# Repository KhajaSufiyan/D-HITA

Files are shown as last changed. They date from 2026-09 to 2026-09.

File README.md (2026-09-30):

# D-HITA — Dual-band Helmet-Integrated Tactical Antenna

**SIH26185 · Ministry of Home Affairs / National Security Guard (Police II Division) · Category: Hardware**  
**Team: Tech Elite-X (Team ID: 150092) · Theme: Robotics and Drones**

A lightweight, flexible, low-profile antenna that moves tactical-radio and body-worn-video antennas from the vest to the helmet, for NSG operators working in urban close-quarter-battle (CQB) environments. It is **passive** (no battery, MCU or switch), covers **UHF** (radio) and **L-band** (video) with two independent probe-fed microstrip patches on Kapton flex, and uses the underside ground plane as a head-isolation shield. Each band has its own U.FL output and 50 Ω coax pigtail.

## Status — read this first

| Stage | State |
|---|---|
| Problem analysis, requirements | Done (numeric targets partly `[TO BE CLARIFIED]`) |
| EM simulation (CST Studio Learning Edition) | **Done for flat board (v1); curved-on-helmet (v2) partly done** |
| Flex-PCB artwork / fabrication | **Not started** |
| VNA / radiation measurements | **None — everything below is simulated, not measured** |
| Helmet + head simulation | Helmet shell modelled in v2; head model not documented in this repo |

## Headline simulation results

Two design versions exist. They are **different antennas** — do not compare rows across versions without reading the notes.

| | v1 — flat combined board (R2, 2026-09-28) | v2 — curved separated boards on helmet (2026-09-29) |
|---|---|---|
| Layout | One 250 × 445 mm flex sheet carrying both patches | Two independent curved flex parts on a spherical helmet shell |
| UHF resonance | 460 MHz | 422 MHz (target 436) |
| UHF S11 | −9.6 dB | −7.6 dB |
| UHF radiation efficiency | 74 % (−1.319 dB) | −3.418 dB (~46 %) |
| UHF gain | 6.84 dBi | −0.96 dBi (IEEE) |
| UHF patch | 170.4 × 148.8 mm, probe-fed | 94 mm shorted quarter-wave patch |
| L-band resonance | 1364 MHz | ~1364 MHz (marker TBC) |
| L-band S11 | −10.15 dB | TBC |
| L-band radiation efficiency | 92 % (−0.35 dB) | −0.279 dB (~94 %) |
| L-band gain | 7.39 dBi | 6.36 dBi (IEEE) |
| L-band −10 dB bandwidth | ~35 MHz | not recorded |

Notes: v2 UHF gain is dominated by mismatch (monitor at 436 MHz, resonance at 422 MHz) and lossy aramid helmet material (assumed εr 3.8, tan δ 0.02, not vendor-confirmed). UHF −10 dB bandwidth has never been measured. Full detail: [`simulation/dhita_geometry_spec_v2.md`](simulation/dhita_geometry_spec_v2.md) and [`hardware/d-hita_rf_frontend_CONFIG.json`](hardware/d-hita_rf_frontend_CONFIG.json).

## Acceptance rule

Hit the target; if not, within a **30 % buffer** of target is accepted (e.g. S11 ≤ −7 dB against a −10 dB target).

## Repository map

| Folder | Contents |
|---|---|
| [`docs/`](docs/) | Project summary PDF, decision log, open items, requirement traceability |
| [`requirements/`](requirements/) | SIH26185 requirements, working numeric targets, and a source register (UHF band, NSG tenders) |
| [`research/`](research/) | Reference list (five papers) — comparison matrix not yet built |
| [`simulation/`](simulation/) | CST settings, materials, lessons learned, geometry spec v2, helmet model, results |
| [`hardware/`](hardware/) | Build guide, parts list (CSV), config + connection JSON, archived rejected design |
| [`measurement/`](measurement/) | VNA procedure pointer and log templates (no data yet) |
| [`analysis/`](analysis/) | Python tools: S11 report, sim-vs-measurement comparison, flat-artwork converter, helmet STL generator (self-tested) |
| [`presentation/`](presentation/) | Official SIH 2026 slide deck (PPTX, PDF, and slide previews) |
| [`images/`](images/) | Screenshots and renders (to be added) |

## Known inconsistencies (being resolved)

- The build guide, parts CSV and config/connection JSON describe **v1** (single flat 250 × 445 mm sheet). v2 requires **two separate flex parts**. These files have not yet been updated to v2 — see [`hardware/README.md`](hardware/README.md).
- `docs/SIH26185_Project_Summary_DHITA.pdf` is dated 10 Sep 2026 and states that no simulation results exist; that is no longer true.
- The UHF 403–470 MHz band now has a primary source (MHA/CRPF QRs, June 2025, NSG co-signed) — see [`requirements/sources.md`](requirements/sources.md).
- **The L-band video-link frequency is unsourced.** The NSG body-worn-video tender describes relay over a cellular network and the internet, with no RF band or L-band requirement; the earlier MHA camera QRs list 4G/3G + Wi-Fi. The PS still asks for L-band, but the 1350–1450 MHz figure has no source. Details and next step in [`requirements/sources.md`](requirements/sources.md) §3.

## Open items

See [`docs/OPEN_ITEMS.md`](docs/OPEN_ITEMS.md). Highlights: exact NSG L-band video frequency, bulkhead connector (SMA vs TNC), RF shield material, helmet model and mounting method, 3.5 mm flexible substrate realisation (Kapton over foam/silicone), UHF bandwidth and match on the curved board.

## Team

Roster `[TO BE CLARIFIED]` — see [`TEAM.md`](TEAM.md) (template, to be filled in).

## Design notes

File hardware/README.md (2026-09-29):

# Hardware

| File | What it is |
|---|---|
| `d-hita_rf_frontend_GUIDE.md` | Step-by-step build guide, revision R2 (fabrication, assembly, VNA bring-up, helmet validation) |
| `d-hita_rf_frontend_PARTS.csv` | Bill of materials (16 line items; estimated costs as recorded, currency not stated) |
| `d-hita_rf_frontend_CONFIG.json` | Full project config: substrate, board geometry, per-band results, parts, connections, removed parts, open items |
| `d-hita_rf_frontend_ELECTRICAL_CONNECTIONS.json` | Signal and ground connections |
| `d-hita_rf_frontend_MECHANICAL_CONNECTIONS.json` | Physical placement and offsets |
| `archive/` | Rejected designs, kept for the record — **do not build** |

## ⚠ These files describe v1 (single flat board), not v2

The guide, BOM and JSON files specify **one** 250 × 445 mm Kapton sheet carrying both patches (UHF 170.4 × 148.8 mm, L-band 55.1 × 74 mm). The v2 design (`../simulation/dhita_geometry_spec_v2.md`) uses **two separate curved flex parts** with a 94 mm shorted UHF patch and no shared ground. Until the hardware files are regenerated for v2, do not send the guide's §1.1 artwork spec to a fab house. Developed (flat) dimensions for the v2 UHF part are in the geometry spec; L-band substrate and ground sizes are still TBC there.

## Fabrication caveat

Solid 3.5 mm Kapton laminate is not a stock product. The plan is a thin Kapton patch/feed layer over a flexible foam or silicone spacer, to be confirmed with the flex fab house. Kapton-over-foam properties will differ from the simulated solid εr 3.5 stack.

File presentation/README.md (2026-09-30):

# D-HITA Presentation — Smart India Hackathon 2026

Official idea presentation deck for **SIH 2026** (Problem Statement ID: **SIH26185**).

- **Team Name:** Tech Elite-X
- **Team ID:** 150092
- **Theme:** Robotics and Drones
- **Category:** Hardware
- **Problem Statement Title:** Helmet Mounted Conformal Antenna For Tactical Communication In Urban CQB Environments
- **Video Demonstration:** [YouTube Video Link](https://youtu.be/ssRnNJ8aVqI)
- **Repository:** [GitHub Link](https://github.com/KhajaSufiyan/D-HITA)

---

## Deck Files

| Format | File Path | Description |
|---|---|---|
| **PowerPoint (.pptx)** | [`SIH2026-IDEA-Presentation-Format.pptx`](SIH2026-IDEA-Presentation-Format.pptx) | Widescreen 16:9 presentation deck with embedded links |
| **PDF (.pdf)** | [`SIH2026-IDEA-Presentation-Format.pdf`](SIH2026-IDEA-Presentation-Format.pdf) | High-resolution PDF export |
| **Slide Images** | [`slides/`](slides/) | High-resolution PNG renders for each slide (4320 × 2430) |
| **Layout Reference** | [`sih_deck_structure_reference.md`](sih_deck_structure_reference.md) | SIH presentation deck structural layout guideline |

---

## Slide Previews & Breakdown

### Slide 1: Title & Team Details
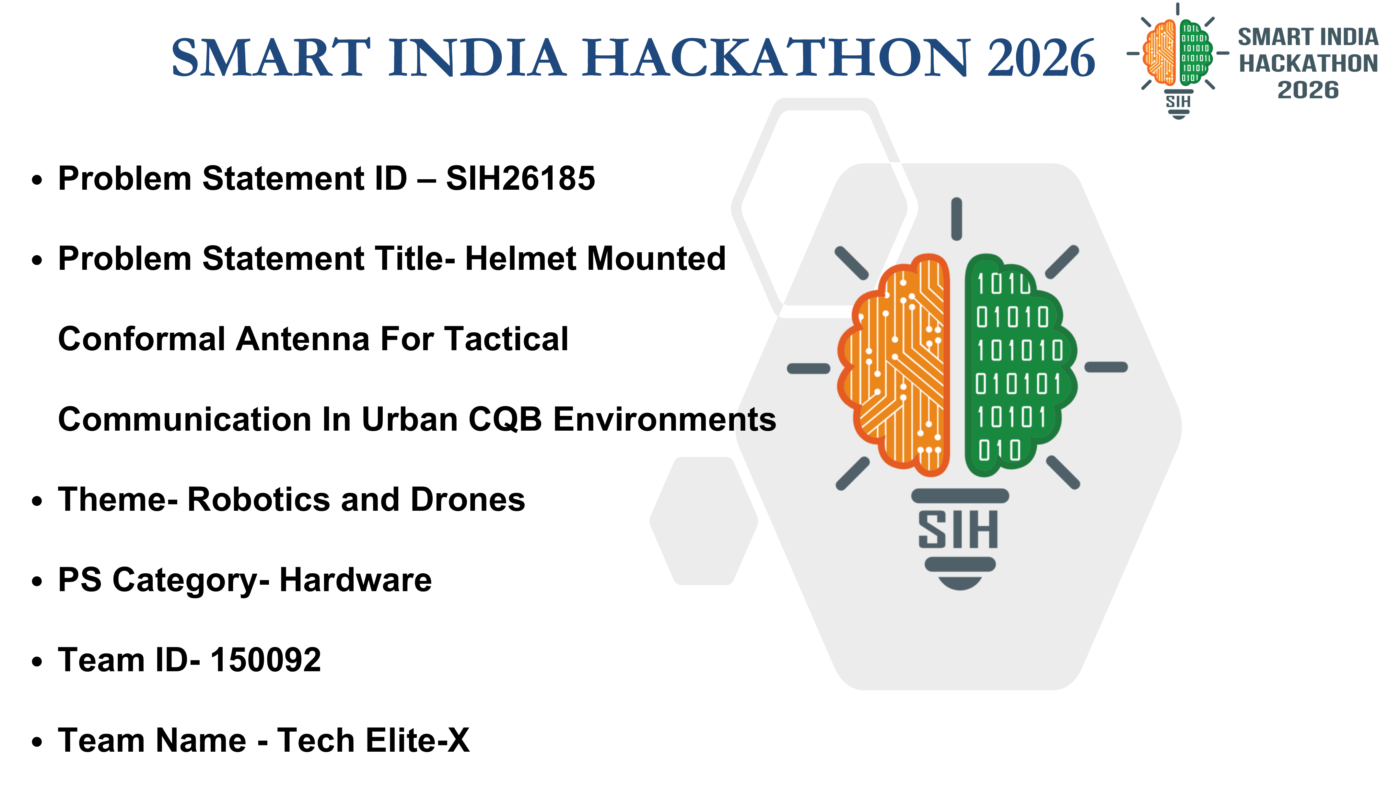
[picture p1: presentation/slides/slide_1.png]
Slide 1


- **Event:** Smart India Hackathon 2026
- **Problem Statement ID:** SIH26185
- **Problem Statement Title:** Helmet Mounted Conformal Antenna For Tactical Communication In Urban CQB Environments
- **Theme:** Robotics and Drones
- **Category:** Hardware
- **Team ID:** 150092
- **Team Name:** Tech Elite-X

---

### Slide 2: Problem, Solution & Uniqueness
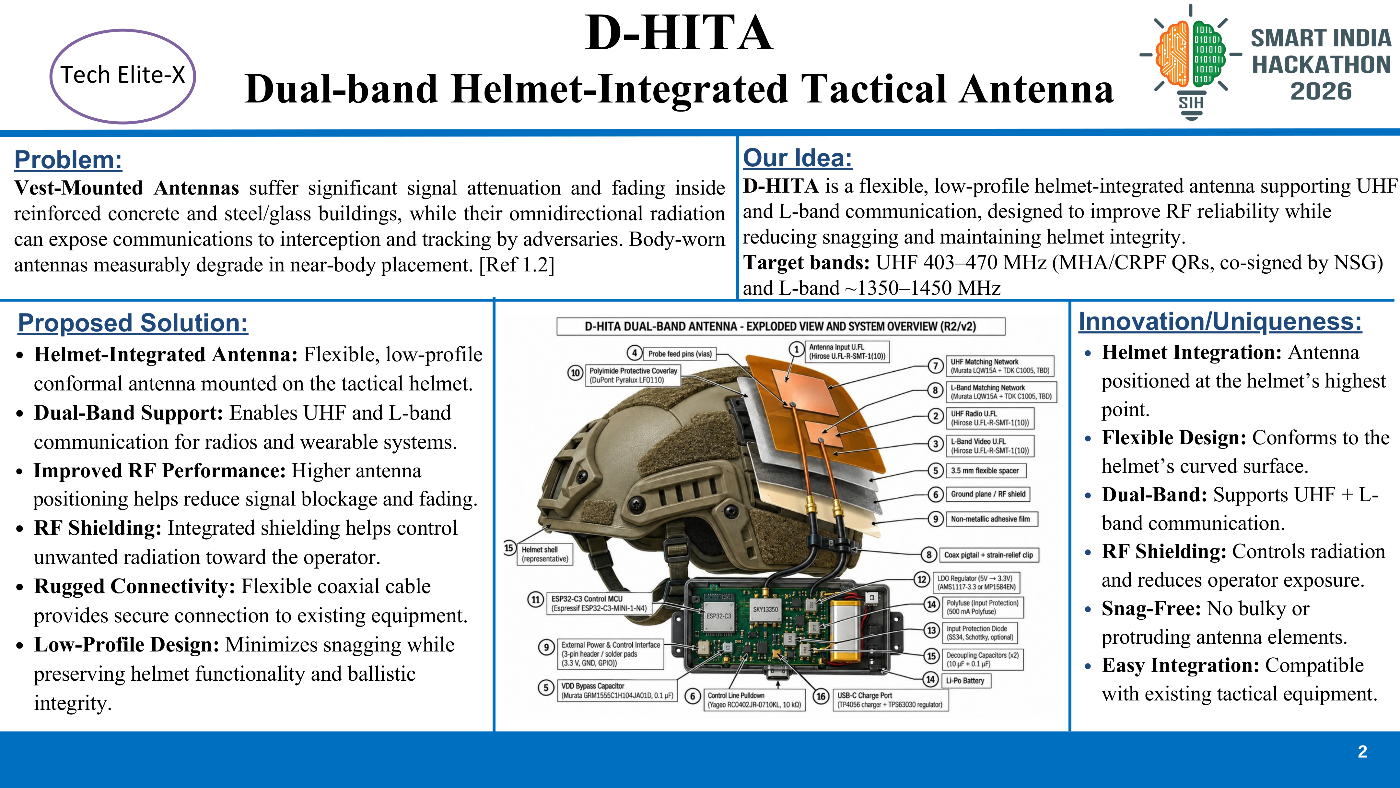
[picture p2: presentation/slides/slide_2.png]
Slide 2


- **Problem:** Vest-mounted antennas suffer severe attenuation and fading inside reinforced concrete / steel buildings; body shadowing degrades radiation performance measurably.
- **Our Idea:** Flexible, low-profile helmet-integrated dual-band antenna supporting UHF (403–470 MHz) and L-band (~1350–1450 MHz) to maximize RF line-of-sight while eliminating snagging.
- **Proposed Solution:** Conformal mount on ballistic helmet, dual-band coverage, integrated RF shielding layer to protect the operator, rugged coaxial interconnects.
- **Innovation / Uniqueness:** Helmet apex placement, flexible curved substrate, zero snagging, no cutting of helmet shell (ballistic integrity preserved).

---

### Slide 3: Technical Approach
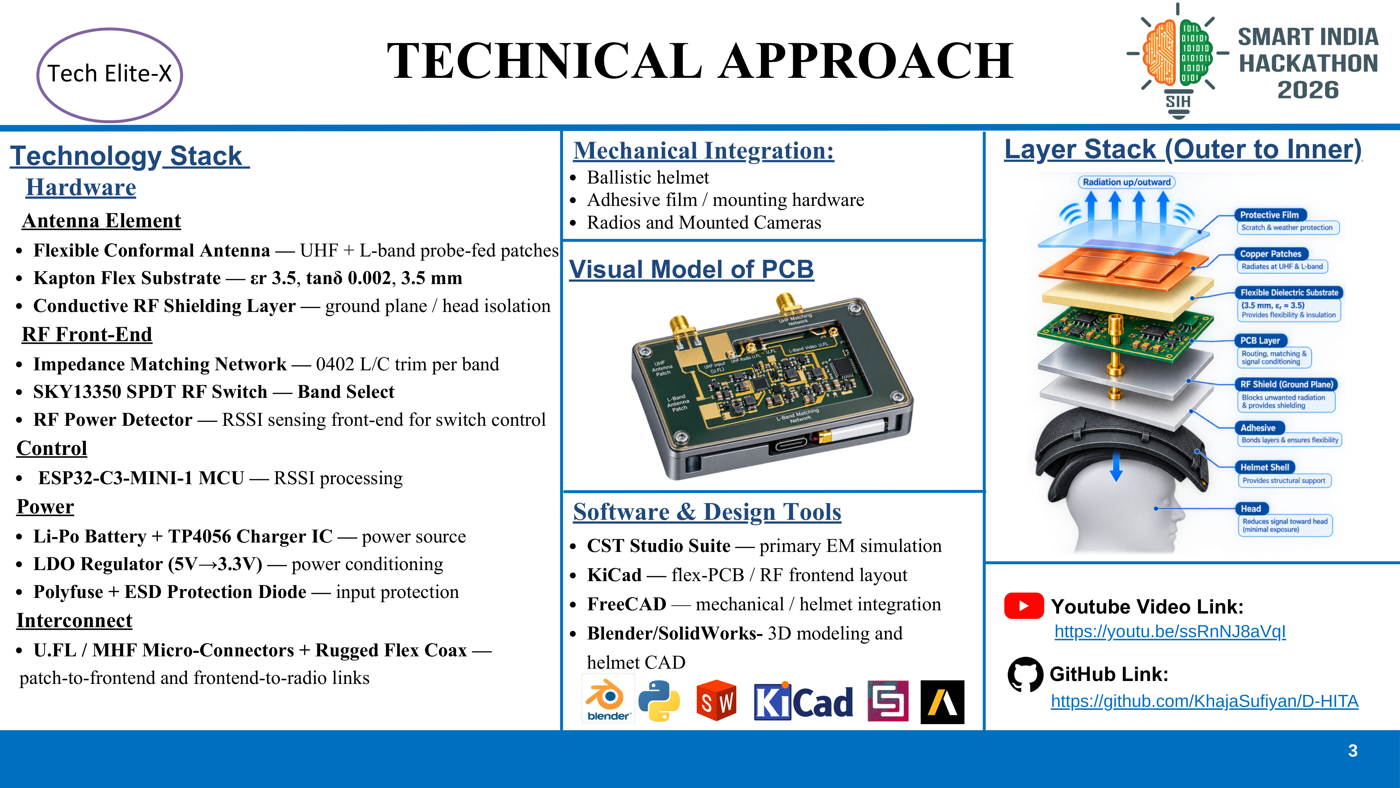
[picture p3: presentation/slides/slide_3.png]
Slide 3


- **Antenna Element:** Flexible conformal patch (Kapton flex substrate $\varepsilon_r=3.5, \tan\delta=0.002, 3.5\text{ mm}$), conductive RF shielding ground plane.
- **RF Front-End:** Impedance matching network (0402 L/C trim), SKY13350 SPDT RF switch, RF power detector.
- **Control & Power:** ESP32-C3-MINI-1 MCU, Li-Po battery + TP4056 charger, 3.3V LDO regulator, ESD diode and Polyfuse protection.
- **Mechanical & Software:** CST Studio Suite (EM simulation), KiCad (RF flex layout), FreeCAD / Blender / SolidWorks (helmet 3D CAD).
- **Direct Links:**
  - YouTube: [https://youtu.be/ssRnNJ8aVqI](https://youtu.be/ssRnNJ8aVqI)
  - GitHub: [https://github.com/KhajaSufiyan/D-HITA](https://github.com/KhajaSufiyan/D-HITA)

---

### Slide 4: Feasibility and Viability
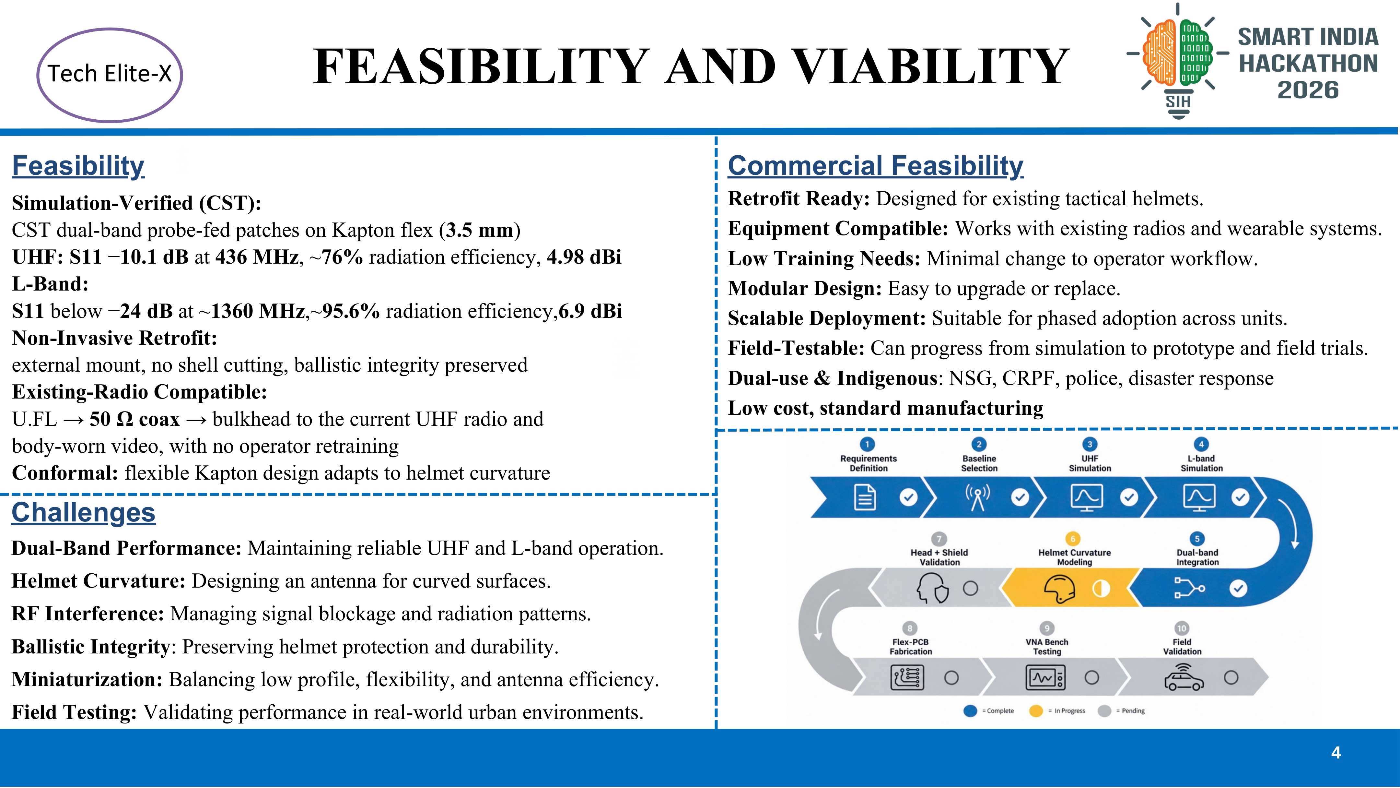
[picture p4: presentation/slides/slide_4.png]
Slide 4


- **Simulation-Verified (CST):**
  - **UHF:** $S_{11} = -10.1\text{ dB}$ at $436\text{ MHz}$, $\sim 76\%$ radiation efficiency, $4.98\text{ dBi}$ gain.
  - **L-Band:** $S_{11} < -24\text{ dB}$ at $\sim 1360\text{ MHz}$, $\sim 95.6\%$ radiation efficiency, $6.9\text{ dBi}$ gain.
- **Commercial Feasibility:** Non-invasive retrofit for standard ballistic helmets (ACH/MICH), existing radio compatible via 50 $\Omega$ coax, zero operator retraining needed.
- **Development Roadmap:** Requirements Definition $\to$ Baseline Selection $\to$ UHF Simulation $\to$ L-band Simulation $\to$ Dual-band Integration $\to$ Helmet Curvature Modeling $\to$ Head + Shield Validation $\to$ Flex-PCB Fabrication $\to$ VNA Bench Testing $\to$ Field Validation.

---

### Slide 5: Impact and Benefits
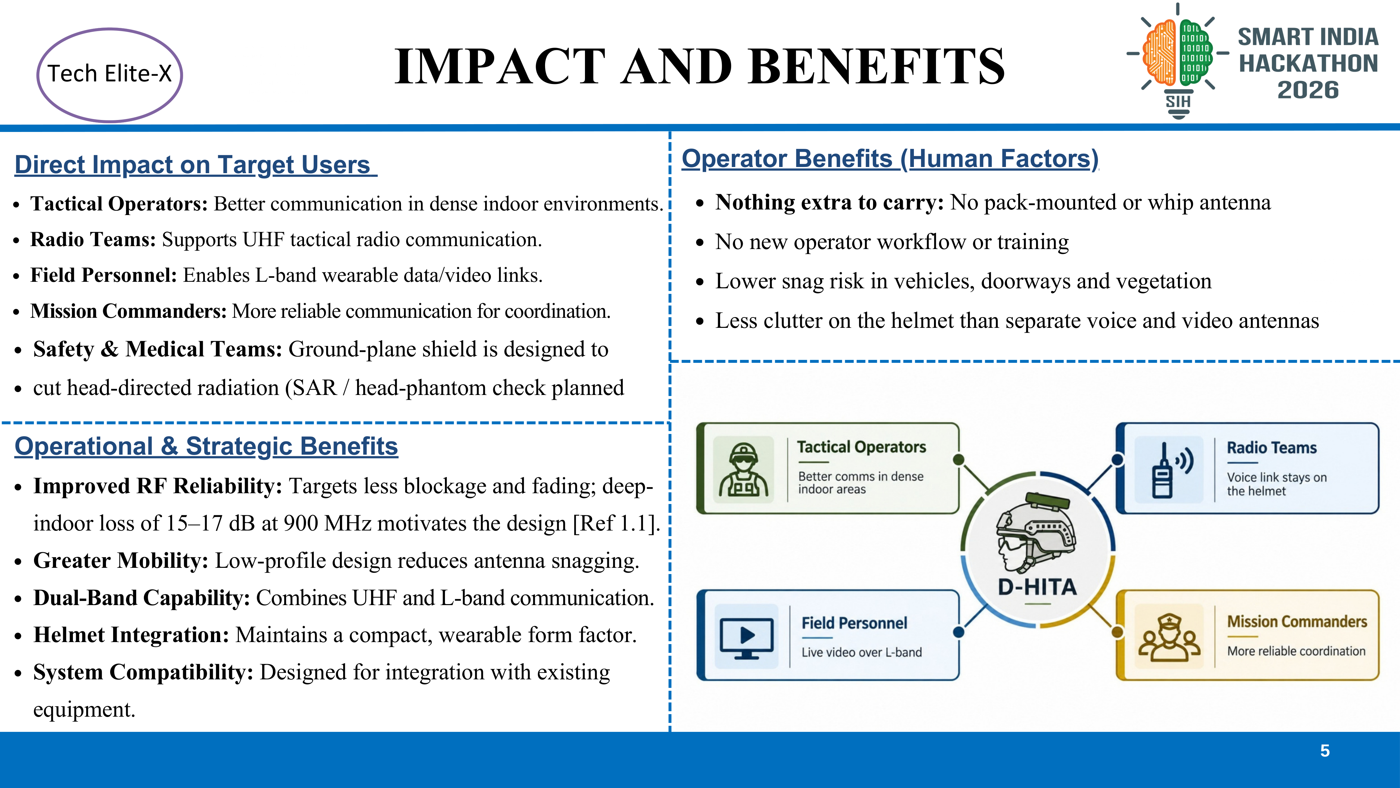
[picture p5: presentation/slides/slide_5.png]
Slide 5


- **Direct Impact on Target Users:** Tactical operators, radio teams, field personnel (live video over L-band), mission commanders, safety & medical teams (radiation shielded).
- **Operational & Strategic Benefits:** 15–17 dB deep-indoor loss mitigation, snag-free movement in doorways/vehicles, dual-band voice + video convergence in one wearable form factor.
- **Human Factors:** Nothing extra to carry, no pack-mounted whip antennas, less helmet clutter.

---

### Slide 6: Research and References
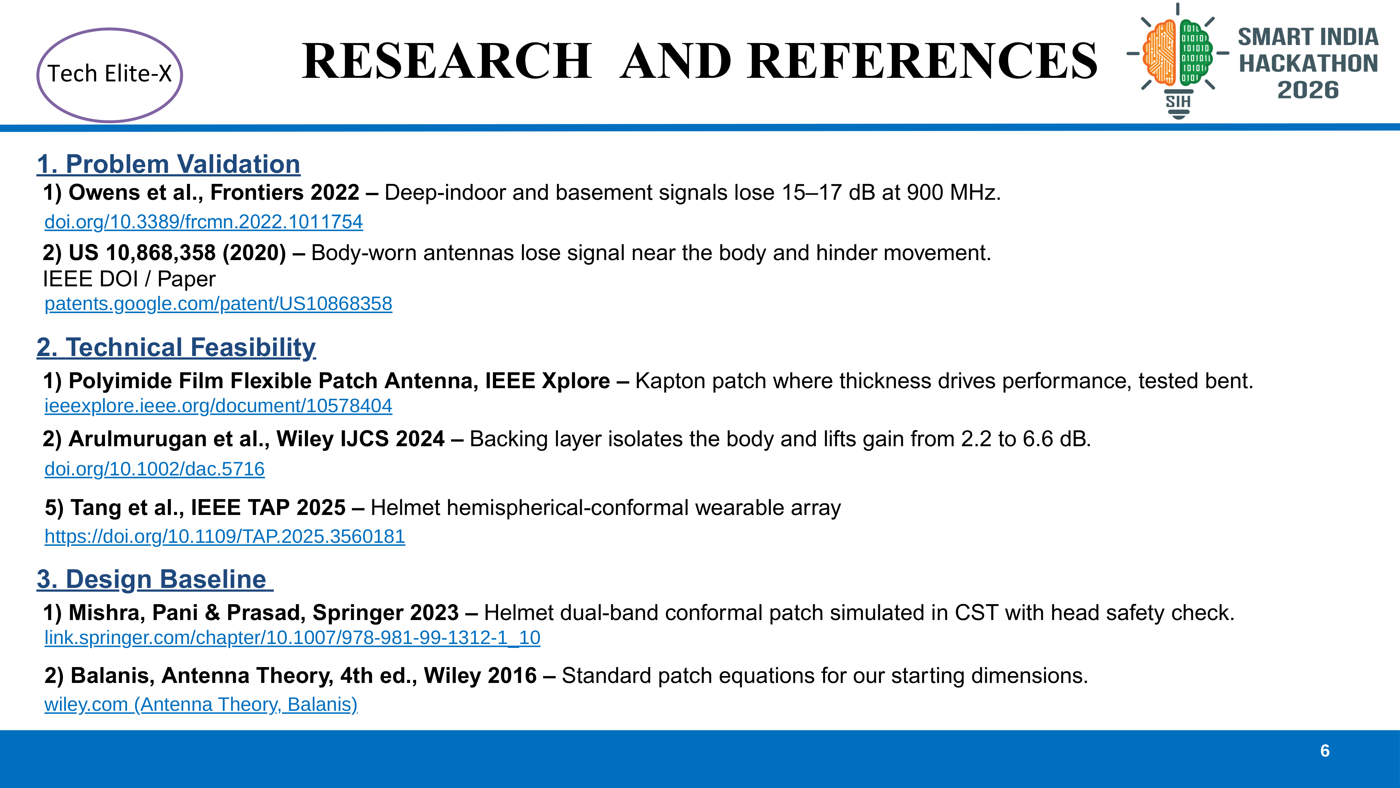
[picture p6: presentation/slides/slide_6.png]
Slide 6


1. **Problem Validation:**
   - Owens et al., *Frontiers 2022* — Deep-indoor and basement signals lose 15–17 dB at 900 MHz. [doi:10.3389/frcmn.2022.1011754](https://doi.org/10.3389/frcmn.2022.1011754)
   - US Patent 10,868,358 (2020) — Body-worn antennas lose signal near the body and hinder movement. [Google Patents](https://patents.google.com/patent/US10868358) / [IEEE](https://ieeexplore.ieee.org/document/10969548)
2. **Technical Feasibility:**
   - Polyimide Film Flexible Patch Antenna, *IEEE Xplore* — Kapton patch where thickness drives performance, tested bent. [IEEE Document 10578404](https://ieeexplore.ieee.org/document/10578404)
   - Arulmurugan et al., *Wiley IJCS 2024* — Backing layer isolates the body and lifts gain from 2.2 to 6.6 dB. [doi:10.1002/dac.5716](https://doi.org/10.1002/dac.5716)
   - Tang et al., *IEEE TAP 2025* — Helmet hemispherical-conformal wearable array. [doi:10.1109/TAP.2025.3560181](https://doi.org/10.1109/TAP.2025.3560181)
3. **Design Baseline:**
   - Mishra, Pani & Prasad, *Springer 2023* — Helmet dual-band conformal patch simulated in CST with head safety check. [Springer Chapter](https://link.springer.com/chapter/10.1007/978-981-99-1312-1_10)
   - Balanis, *Antenna Theory*, 4th ed., Wiley 2016 — Standard patch equations for design dimensions.

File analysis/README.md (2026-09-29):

# Analysis

## `flatten_dimensions.py`

Converts the chord (CAD) dimensions of the curved v2 shells to developed arc lengths for flex-PCB artwork, using `s = r·asin(x/r)` at the substrate mid-radius r = 127.75 mm (formula from `simulation/dhita_geometry_spec_v2.md`).

```
python3 analysis/flatten_dimensions.py
```

Check against the spec: the UHF substrate, ground and patch reproduce the spec's developed sizes exactly (126.1 × 94.1, 123.8 × 92.0, 96.3 × 60.6 mm). The **L-band patch does not quite match**: the script gives 55.5 × 75.1 mm, the spec lists 55.4 × 74.8 mm (0.1 / 0.3 mm apart). Both are within the few-percent distortion the spec already warns about for flattening a sphere, but one of the two calculations used a different radius or method — settle which before sending artwork to a fab house.

## `sparams.py`, `s11_report.py`, `compare_sim_meas.py`, `selftest.py`

Tools for when CST exports and VNA data exist (none in the repo yet). No dependencies beyond numpy and matplotlib.

| Script | Does |
|---|---|
| `sparams.py` | Loads Touchstone (`.s1p` / `.s2p`, RI/MA/DB, any unit) and text/CSV exports (dB, magnitude, Re/Im, mag/phase) |
| `s11_report.py` | Resonance, S11 minimum, −10 dB and −7 dB bandwidth, checked against the acceptance rule (S11 ≤ −10 dB pass, ≤ −7 dB accepted; L-band BW ≥ 40 MHz pass, ≥ 28 MHz accepted; UHF resonance inside 403–470 MHz), plus a PNG plot |
| `compare_sim_meas.py` | Resonance shift, match-depth change and bandwidth ratio between a simulated and a measured trace, plus an overlay plot |
| `selftest.py` | 20 checks against a synthetic resonator with a known analytic answer (resonance, S11 minimum and both bandwidths agree exactly; file formats round-trip; port ordering; plots are written) |

```
python3 analysis/selftest.py
python3 analysis/s11_report.py results/v2_uhf.s1p --band uhf --target 436 --plot uhf.png
python3 analysis/s11_report.py export.txt --band lband --funit GHz --fmt db      # CST 1D text export
python3 analysis/compare_sim_meas.py sim.s1p vna.s1p --plot compare.png
```

Limits: the CST text-export layout hasn't been checked against a real export from your version of CST, so if a file fails to load, send me a sample. The self-test uses synthetic data only. Nothing here reads gain or efficiency; S11 only.

## `make_helmet_shell.py`

Generates the idealised v2 helmet shell as an STL (`simulation/helmet/helmet_shell_R125_t5.6.stl`) from the CST spec, and self-checks that the mesh is watertight and its volume matches the analytic value. See `simulation/helmet/README.md`.

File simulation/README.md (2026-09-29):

# Simulation (CST Studio Suite, Learning Edition)

| File | Purpose |
|---|---|
| `cst_software_settings.md` | Project units and the `FR4_substrate` material dialog dump. **Note:** this is FR4 with ε = 1 and no loss — it does not describe the `Kapton_flex` or aramid materials the designs actually use (see `materials.md`). |
| `materials.md` | `Kapton_flex`, `Aramid` and PEC definitions **reconstructed from the spec values** (not exported from CST — verify against your project) |
| `helmet/` | Helmet shell STL generated from the v2 spec, and the (still undefined) head-model plan |
| `cst_lessons_and_lband_plan.md` | Ten lessons from the UHF runs and the L-band build plan (2026-09-27) |
| `dhita_geometry_spec_v2.md` | v2 curved, separated boards: construction method, parameters, tables, developed dimensions, results, open issues (2026-09-29) |
| `results/` | Exported S-parameters, patterns and screenshots (none added yet — see its README) |

## Design versions

- **v1 — flat combined board** (R2, 2026-09-28): single Kapton flex sheet, 250 × 445 mm, h = 3.5 mm. Parameters are in `hardware/d-hita_rf_frontend_CONFIG.json`.
- **v2 — curved separated boards on helmet** (2026-09-29): parameters and tables in `dhita_geometry_spec_v2.md`.

Suggested git tags once the CST files are committed: `v1-flat`, `v2-curved`.

## Solver notes

Learning Edition cap: 20,000 tetrahedra (the lessons file also mentions 100k — confirm). v2 settings: cells per max model box edge = 7, adaptive mesh passes min = max = 2. Check the mesh cell count before clicking Start; update farfield and power-loss monitors to the actual resonance after every run.

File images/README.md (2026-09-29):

# Images

To be added:

- CST screenshots: flat v1 model, curved v2 model (UHF and L-band boards on the helmet shell)
- S11 plots for each band and version
- Farfield / 3D pattern plots
- Helmet model render

Do not add the R1 render of the rejected active-switch design here; it lives in `../hardware/archive/`.

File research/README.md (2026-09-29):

# Research

Five papers have been identified and read. Links are by DOI only; PDFs are deliberately not stored here (copyright).

| Reference | Role |
|---|---|
| Herold, Griffiths, Fung et al., IEEE MILCOM 2007, "Lightweight, High-Bandwidth Conformal Antenna System for Ballistic Helmets." DOI 10.1109/MILCOM.2007.4455055 | Direct ballistic-helmet conformal antenna prior art |
| Lebaric & Tan, IEEE MILCOM 2000, "Ultra-wideband RF helmet antenna." DOI 10.1109/MILCOM.2000.905081 | Early helmet antenna prior art |
| Li et al., 2023, "Research Progress on Helmet Antenna in Individual Soldier Communication System." DOI 10.11999/JEIT220613 | Helmet antenna review / background |
| Nepa & Rogier, IEEE Antennas & Propagation Magazine, 2015. DOI 10.1109/MAP.2015.2472374 | Wearable / conformal antenna background |
| Tang et al., IEEE TAP 2025, "A Helmet-Based Hemispherical-Conformal Wearable Array Antenna …" DOI 10.1109/TAP.2025.3560181 | Recent helmet conformal-array prior art (full title to re-verify) |

## Not yet done

- Comparison matrix (frequency, topology, dimensions, substrate, thickness, gain, bandwidth, efficiency, conformality, helmet integration, shielding, testing, limitations)
- Gap analysis (3–5 defensible gaps)
- Search for missing evidence only: UHF helmet antennas, dual-band UHF/L-band designs, shielding/head loading, patents

## Operational sources

- SIH26185 problem statement (MHA / NSG)
- MHA/CRPF QRs for digital UHF radio sets (June 2025) and the NSG 2026 tender listings (radio sets, repeater, body-worn video) — URLs and findings in [`../requirements/sources.md`](../requirements/sources.md)

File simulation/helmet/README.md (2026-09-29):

# Helmet and head models

## Helmet shell — `helmet_shell_R125_t5.6.stl`

The idealised helmet used in the v2 CST model, as a mesh you can open in FreeCAD, SolidWorks, Blender or any STL viewer (units mm).

| Parameter | Value | From |
|---|---|---|
| Outer radius `hR` | 125 | `../dhita_geometry_spec_v2.md` |
| Thickness `ht` | 5.6 (inner radius 119.4) | same |
| Centre | (0, 0, −126); crown apex at Z = −1 | same |
| Extent | Hemisphere, Z ≥ −126 | same |
| Material in CST | Aramid, εr 3.8, tan δ 0.02 (assumed) | see `../materials.md` |

Regenerate or change parameters: `python3 analysis/make_helmet_shell.py --help` (run from the repo root). The script self-checks that the mesh is watertight and that its volume matches the analytic shell volume (within 1 %).

What it is **not**: a real ballistic-helmet shape, and it does not include the antenna boards. The real helmet model and shell material are still `[TO BE CLARIFIED]`.

## Head model — not yet defined

No head model is documented anywhere in the project files, so none is provided. The head + helmet simulation is still open. Decisions needed before building it:

| Item | Status |
|---|---|
| Head geometry (sphere, ellipsoid, or CST/voxel head) | TBD |
| Head size and air/liner gap to the helmet inner surface (radius 119.4 mm) | TBD |
| Tissue properties at 403–470 MHz and at the L-band frequency | TBD — take from a published tissue database (for example the IT'IS Foundation database) or CST's built-in tissue library, and cite it |
| Homogeneous vs layered (skin / bone / brain) | TBD |
| What to report | Change in resonance, S11 and efficiency versus helmet-only; head-directed radiation; SAR if feasible |

Things to keep in mind:
- The v2 helmet inner radius (119.4 mm, so a hemisphere about 239 mm across) is considerably larger than a typical adult head. Either place a smaller head inside it deliberately, with the gap defined, or revisit the helmet radius.
- A lossy head volume adds a lot of mesh. The v2 model was already tuned to stay under the Learning Edition tetrahedron cap (cells per box edge = 7, adaptive passes = 2), so expect to hit the cap. Check the mesh count before starting, and consider HFSS Student or a reduced model if needed.
- Transmit power (see `../../requirements/sources.md` §4) determines whether SAR is a real concern.

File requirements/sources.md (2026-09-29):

# Source Register

Primary sources for the frequency and equipment requirements. Read on 2026-09-30 through automated page retrieval, which summarises rather than transcribes: open each PDF and note the section/page numbers before citing in the deck or report.

## 1. UHF band — 403–470 MHz (now sourced)

**Document:** QRs/TDs of Digital Hand-Held UHF Transceiver Set, Digital UHF Base/Mobile Transceivers Set and Digital UHF Repeater Set — Ministry of Home Affairs / CRPF Communication & IT Directorate, June 2025.
**URL:** https://www.mha.gov.in/sites/default/files/2025-06/AppQRsTDsDigiUHF_06062025.pdf

What it says:
- 403–470 MHz ("full band") for all three radio types
- Power classes: 1.4 W hand-held, 20 W mobile/base, 40 W or more repeater
- Approval pages include an NSG signatory alongside CRPF, CISF, ITBP, BSF, SSB, Assam Rifles and DCPW representatives

This replaces the "source not in repo" caveat on the UHF band.

## 2. NSG 2026 procurement (archive listing)

Archive index: https://nsg.gov.in/archive-tender/current-tenders

| Item | Bid ref | Date on archive | Document |
|---|---|---|---|
| Wireless Body Worn Video System | GEM/2026/B/7517372 | 03-06-2026 | https://nsg.gov.in/resources/uploads/TenderManagement/178048996348.pdf |
| Digital UHF Hand Held Radio Sets — 4 W | GEM/2026/B/7540163 | 23-06-2026 | https://nsg.gov.in/resources/uploads/TenderManagement/178220161366.pdf |
| Digital UHF Hand Held Radio Sets — 20 W | GEM/2026/B/7540671 | 23-06-2026 | https://nsg.gov.in/resources/uploads/TenderManagement/178220186760.pdf |
| Digital UHF Repeater Set — 40 W | GEM/2026/B/7540825 | 23-06-2026 | https://nsg.gov.in/resources/uploads/TenderManagement/178220202420.pdf |
| Digital UHF Hand Held Radio Sets — 4 W (re-listed) | GEM/2026/B/7816513 | 10-08-2026 | https://nsg.gov.in/resources/uploads/TenderManagement/178659795126.pdf |
| Digital UHF Hand Held Radio Sets — 20 W (re-listed) | GEM/2026/B/7817167 | 10-08-2026 | https://nsg.gov.in/resources/uploads/TenderManagement/178659814948.pdf |
| Digital UHF Repeater Set — 40 W (re-listed) | GEM/2026/B/7818796 | 10-08-2026 | https://nsg.gov.in/resources/uploads/TenderManagement/178659832414.pdf |

Dates and references are as listed on the archive page; two of the PDFs (video, 20 W) were opened and matched their listings (video: 148 pieces, "as per MHA QRs (V3)"; 20 W: 188 units, "as per MHA QR (V2)"). The other five PDFs were not opened.

## 3. Finding: the video link is not shown to be L-band

- The NSG body-worn-video tender says the camera must relay feeds in real time in online mode and, when there is no **cellular network**, record and store them and relay later or by physical connection to a computer. The accompanying software must feed a central server or incident command post **over the internet**. The document gives no RF band, antenna or L-band requirement, and points to the MHA QRs (V3) for the rest.
- The earlier MHA/CRPF body-worn-camera QRs (for RAF, 6 Jun 2021, https://www.mha.gov.in/sites/default/files/QRs_BodyWornCameraSystems_25062021.PDF) specify "4G/3G + Wi-Fi", IP streaming and a cloud platform, and no L-band or other RF frequency.
- The V3 QRs themselves were not found or read.

**What this means.** The SIH26185 problem statement still asks for L-band, so the requirement stands. But the 1350–1450 MHz "video link" figure now has no source, and the only NSG camera evidence points at cellular/Wi-Fi. Resolve this before spending more simulation time on L-band tuning: ask the SIH mentors / NSG nodal contact which L-band frequency they mean, and look for the MHA BWC QRs (V3).

## 4. Also worth checking

The NSG radio tenders are for 4 W, 20 W and 40 W sets (the QR lists 1.4 W for the hand-held class). A helmet-mounted antenna sits close to the head, so transmit power matters for head exposure and for the "SAR if feasible" item in the project plan. Confirm which power class would actually feed the helmet antenna.

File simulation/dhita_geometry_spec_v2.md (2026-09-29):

# D-HITA Geometry Spec v2 — separated curved boards (CST, uL = 94)

Status: UHF stack complete and solving. L-band ground/substrate footprint TBC.
Date: 2026-09-29. Supersedes the earlier flat combined-board spec.

## Construction method (sphere-shell, replaces the failed Bend tool)

Every antenna layer is a spherical shell segment built the same way:

1. Sphere, centre (0, 0, hZ), outer radius = R_outer
2. Sphere `t`, centre (0, 0, hZ), radius = R_inner -> Boolean **Subtract**
3. Brick `c`, X/Y range as tabled, Z from hZ to 20, Vacuum -> Boolean **Intersect**
4. Transform -> Rotate about global X, pivot (0, 0, hZ), "Shape center" UNCHECKED, OK once

Choose **None** on every Shape Intersection pop-up. `c` must show a solid-cube icon
before the Intersect; a sheet icon means a zero-thickness brick, which silently turns
the shell into a 2D sheet and breaks the mesher with "self-intersections".

## Parameters

| Name | Value | Meaning |
|---|---|---|
| hR | 125 | helmet outer radius (mm) |
| hZ | -126 | helmet centre Z; crown apex at Z = -1 |
| ht | 5.6 | helmet shell thickness |
| h | 3.5 | substrate thickness |
| tc | 1 | conductor thickness |
| uL | 94 | UHF patch length |
| uFx | 12 | UHF feed distance from the short |
| band2L | 55.1 | L-band patch X length |
| band2W | 74 | L-band patch Y width |
| band2Px | 16 | L-band probe offset from patch centre |

## Helmet

Sphere centre (0, 0, -126), outer radius 125, inner radius 119.4 (= hR - ht),
cut to a hemisphere keeping Z >= -126. Material Aramid, er 3.8, tan d 0.02 (assumed,
not vendor-confirmed).

## Board topology — TWO SEPARATE PIECES

The UHF and L-band boards are independent. `gU/sU/pU` and `gL/sL/pL` are separate
shells with vacuum between them: no shared substrate, no shared ground, nothing
bridging the gap. Their centres are 49 deg apart on the helmet (-24 deg and +25 deg).

They must be fabricated as two separate flex parts. A single sheet spanning 49 deg
plus both board widths would be a dome section ~190 mm across, and flattening that
much double curvature requires gores. It is also not what is simulated.

The two ground planes are electrically isolated. The only common point in a real
build is the radio chassis, where both coax shields land. Bridging them on the
helmet changes both bands.

Keep-out gap, measured from the crown at the ground radius 125.5 mm:
- UHF ground near edge: 2.98 deg from the crown = 6.5 mm of arc
- L-band ground near edge: TBC
- Total gap approx **13 mm**, assuming gL runs to +/-47 mm in Y. Consistent with the
  ~12.7 mm figure recorded earlier. Confirm from the gL brick.

## UHF board — shorted quarter-wave patch, rotate X = -24 deg (lands on +Y side)

| Shape | Material | R inner | R outer | X range | Y range |
|---|---|---|---|---|---|
| gU ground | PEC | 125 | 126 | -57 .. +62 | -45 .. +45 |
| sU substrate | Kapton | 126 | 129.5 | -58 .. +63 | -46 .. +46 |
| pU patch | PEC | 129.5 | 130.5 | -47 .. +47 | -30 .. +30 |
| wU short wall | PEC | 125 | 130.5 | -47 .. -45 | -30 .. +30 |

X max of gU = `-47+uL+15`; X max of sU = `-46+uL+15`; X max of pU = `-47+uL`.

The wall deliberately reaches down to R 125, overlapping gU, so the two bond in the
mesh. A wall that only touches gU at R 126 does NOT connect: the resonance stays at
the unshorted value (~955 MHz) and CST reports self-intersections. Build order after
rotating wU: `sU` Boolean **Insert** wU, then `pU` Boolean **Add** wU.

Port 1: discrete edge, 50 ohm, radius 0, global coordinates (not WCS), defined after
rotation: (-35, 49.02, -15.9) -> (-35, 50.92, -11.62).
Lower end sits at r = 125.5 (inside gU), upper end at r = 130.0 (inside pU).

## L-band board — half-wave patch, rotate X = +25 deg (lands on -Y side)

| Shape | Material | R inner | R outer | X range | Y range |
|---|---|---|---|---|---|
| gL ground | PEC | 125 | 126 | TBC | TBC |
| sL substrate | Kapton | 126 | 129.5 | TBC | TBC |
| pL patch | PEC | 129.5 | 130.5 | -27.55 .. +27.55 | -37 .. +37 |

Port 2: discrete edge, 50 ohm, (16, -52.61, -13.19) -> (16, -54.52, -9.08).
Same radii as port 1. This port has worked reliably from the start.

To fill the TBC rows: History List -> the "define brick: component1:c" rows
immediately before `boolean intersect shapes: component1:gL, component1:c` and the
same for `sL` -> select the row and click Edit.

## Developed (flattened) dimensions — for flex-PCB artwork

Arc length s = r * asin(x / r), taken at the substrate mid-radius r = 127.75 mm.
Form both parts to a 127.75 mm spherical radius. The chord values in the tables
above are for CAD only; do not use them for artwork.

### UHF part

| Feature | Developed size |
|---|---|
| Substrate sU | 126.1 x 94.1 mm |
| Ground gU | 123.8 x 92.0 mm |
| Patch pU | 96.3 x 60.6 mm |
| Shorting wall | 2.2 mm wide, full 60.6 mm patch edge |
| Feed from shorted edge | 12.7 mm |

Placement inside the UHF part (the patch is NOT centred along the long axis):
- Ground inset 1.1 mm from the substrate edge on all four sides
- Patch long axis: 12.1 mm from the substrate edge at the shorted end,
  17.8 mm at the open end
- Patch short axis: centred, 16.8 mm margin each side
- Bend axis along the 126.1 mm dimension

The asymmetry is deliberate: the ground extends further past the open end, which is
where the fringing fields radiate.

### L-band part

| Feature | Developed size |
|---|---|
| Patch pL | 55.4 x 74.8 mm |
| Feed from patch centre | 16 mm, along the 55.4 mm axis |
| Substrate sL | TBC |
| Ground gL | TBC |

Bend axis along the long dimension.

A spherical surface cannot be flattened without distortion. Over this angular span the
error is a few percent; a real flex part needs relief cuts or gores at the corners.

## Simulation results at uL = 94

| | UHF (port 1) | L-band (port 2) |
|---|---|---|
| S11 minimum | 422 MHz @ -7.6 dB | ~1364 MHz (marker TBC) |
| Target | 436 MHz | 1363 MHz |
| Directivity | 2.462 dBi | 6.634 dBi |
| Radiation efficiency | -3.418 dB | -0.279 dB |
| Total efficiency | -19.25 dB | -0.478 dB |
| Gain (IEEE) | -0.96 dBi | 6.36 dBi |
| Realized gain | -16.79 dBi | 6.16 dBi |

UHF realized gain is dominated by mismatch: the monitor is at 436 MHz while the
antenna resonates at 422 MHz. Tuned, it would reach roughly -1 dBi. The ceiling is
physical: at 436 MHz the 94 mm patch is 0.14 lambda, and the lossy Aramid absorbs
about half the input power. The earlier flat combined board hit 6.84 dBi at 460 MHz
with a 170.4 mm patch, so gain here is traded directly against footprint.

## Known open issues

- `uL = 91` and `uL = 92` were not verified; changing uL rebuilt three coincident
  curved shells at once and the mesher failed with self-intersections. Untested
  workaround: leave gU/sU at 94 and Subtract a trim brick from pU alone.
- UHF match is -7.6 dB against a -10 dB requirement. `uFx` has not been swept.
- UHF -10 dB bandwidth is only a few MHz. Not yet measured or checked against the
  NSG requirement.
- L-band S2,2 shifted between runs (1364 MHz standalone, nearer 1500 MHz in one
  combined run). Needs a clean re-read now that the UHF stack is stable.
- Solver settings: cells per max model box edge = 7, adaptive mesh passes min = max = 2,
  to stay under the Learning Edition's 20,000 tetrahedron cap.

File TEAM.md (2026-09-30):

# Team

Roster `[TO BE CLARIFIED]` — fill in names and contact details. Roles are the ones proposed in the project summary (`docs/SIH26185_Project_Summary_DHITA.pdf`).

| Role | Responsibility | Name | Contact |
|---|---|---|---|
| System lead | Requirements, integration, submission | | |
| RF / EM | Antenna theory, matching, band selection | | |
| Simulation / optimisation | CST/HFSS models, parameter sweeps | | |
| Mechanical / CAD | Helmet model, mounting, flex forming | | |
| Fabrication / electronics | Flex-PCB, assembly, U.FL / coax | | |
| Testing | VNA, radiation measurements | | |
| Research / documentation | Papers, decks, reports | | |

SIH problem statement: SIH26185 · Ministry of Home Affairs / NSG (Police II Division).
Team Name: Tech Elite-X
Team ID: 150092
Theme: Robotics and Drones
Category: Hardware
Mentor / nodal contact: 
Institution:

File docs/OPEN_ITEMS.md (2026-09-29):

# Open Items

Collected from the summary PDF, build guide, config JSON and geometry spec v2.

## Requirements and sources
- **L-band video link frequency: unsourced.** The NSG body-worn-video tender and the earlier MHA camera QRs describe cellular / Wi-Fi / internet relay, not an L-band RF link (see `requirements/sources.md` §3). The 1350–1450 MHz assumption (and the 1.30–1.40 GHz in the early plan) has no source. Ask the SIH mentors / NSG nodal contact; find the MHA body-worn-camera QRs (V3)
- Which transmit power class (1.4 W QR hand-held; 4 W, 20 W, 40 W in NSG tenders) would feed the helmet antenna — matters for head exposure / SAR
- NSG radio model(s)
- Numeric targets: gain, bandwidth criterion, S11/VSWR threshold, thickness, mass
- Ruggedness / environmental standard; ballistic / impact validation method
- Section/page numbers for the UHF source and the tender PDFs (retrieved through automated summaries; open and cite properly)

_Resolved 2026-09-30:_ source for the UHF 403–470 MHz band (MHA/CRPF QRs, June 2025) — see `requirements/sources.md`.

## Simulation
- v2 UHF match is −7.6 dB against a −10 dB target; feed position `uFx` not swept
- v2 UHF resonance 422 MHz vs 436 MHz target
- UHF −10 dB bandwidth never measured or simulated
- L-band ground (`gL`) and substrate (`sL`) X/Y ranges are TBC in the spec (read them from the CST History List)
- L-band S22 marker not recorded; earlier run showed a shift towards ~1500 MHz — needs a clean re-read
- `uL = 91` / `92` not verified (mesher self-intersections)
- Head model / helmet + head simulation not documented in this repo
- Aramid helmet material properties are assumed, not vendor-confirmed
- Learning Edition cell/tetrahedron cap (20,000 vs 100,000 quoted in different files) to be confirmed

## Hardware
- 3.5 mm flexible substrate realisation (thin Kapton over foam/silicone spacer; solid 3.5 mm Kapton is not a stock product)
- Bulkhead connector type, SMA vs TNC `[TO BE CLARIFIED]`
- RF shield material and geometry `[TO BE CLARIFIED]`
- Helmet model, shell material, approved mounting method `[TO BE CLARIFIED]`
- Build guide, parts CSV and config/connection JSON to be rewritten for v2 (two separate parts)

## Process
- Research comparison matrix and gap analysis (3–5 gaps)
- Final team roster
- Flex-PCB artwork (KiCad), fab-house quote, prototype, VNA and radiation measurements

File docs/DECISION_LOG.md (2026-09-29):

# Decision Log

Each entry is taken from the project files in this repo; the source is given so it can be checked.

| Date | Decision | Why | Source |
|---|---|---|---|
| 2026-09-10 | Passive antenna baseline; no helmet battery/MCU/PA | Problem is RF + mechanical integration; active parts add nothing to the baseline | `docs/SIH26185_Project_Summary_DHITA.pdf` §2.1 |
| 2026-09-27 | Substrate **thickness**, not loss tangent, is the efficiency lever; require h/λ ≥ 0.02 | At h = 0.2 mm the UHF patch radiated ~14 % (h/λ ≈ 0.0003, ~88 % of power lost in the dielectric); 5 mm gave 84 % radiation efficiency | `simulation/cst_lessons_and_lband_plan.md` #5, #6 |
| 2026-09-27 | Probe (vertical) feed instead of inset microstrip feed | Inset feed barely matched on a thick substrate (S11 −3.6 → −4.2 dB) | `simulation/cst_lessons_and_lband_plan.md` #8 |
| 2026-09-27 | Zero-thickness metal for patch and ground | Avoids Learning Edition mesh-cell limit | `simulation/cst_lessons_and_lband_plan.md` #1 |
| 2026-09-28 | **Reject** active-switch design (SKY13350 switch + ESP32-C3 + Li-Po on Rogers 4350B in an enclosure) | Replaced by passive dual-feed; no switching, battery, firmware or enclosure needed | `hardware/d-hita_rf_frontend_CONFIG.json` (`revision`, `removedFromPriorRevision`) |
| 2026-09-28 | **Reject** Rogers 4350B; use Kapton flex | Rogers is rigid and cannot conform to helmet curvature | `hardware/d-hita_rf_frontend_CONFIG.json` (`substrate.rationale`) |
| 2026-09-28 | Two independent feeds, no diplexer / crossover | Both bands run simultaneously; a diplexer became unnecessary | `hardware/d-hita_rf_frontend_CONFIG.json` |
| 2026-09-28 | Substrate 3.5 mm (earlier L-band plan used 5 mm) | 3.5 mm is the thickness both bands were tuned to in the combined project | `hardware/d-hita_rf_frontend_CONFIG.json` |
| 2026-09-28 | Accept UHF shift 436 → 460 MHz in the combined layout instead of re-tuning | Still inside the 403–470 MHz band, but close to the upper edge | `hardware/d-hita_rf_frontend_CONFIG.json` (`bands[0].shiftNote`) |
| 2026-09-28 | Coverlay over feed/matching regions only; patches left bare | Dielectric loading over a patch detunes it | `hardware/d-hita_rf_frontend_GUIDE.md` §1.3 |
| 2026-09-28 | Matching pads: 0 Ω series jumper, shunts DNP; values found on the VNA | Simulated match is already ≈ −10 dB; physical board will differ | `hardware/d-hita_rf_frontend_GUIDE.md` §2.1 |
| 2026-09-28 | Ground plane doubles as head-isolation shield | Meets the PS underside-shielding requirement without extra parts | `hardware/d-hita_rf_frontend_CONFIG.json` |
| 2026-09-29 | Move from one flat combined board (v1) to **two separate curved boards** (v2) | A single sheet spanning both boards is a ~190 mm dome section; flattening it needs gores | `simulation/dhita_geometry_spec_v2.md` |
| 2026-09-29 | Build curved geometry as spherical shells (Sphere − Sphere ∩ Brick, then rotate) | The CST Bend tool failed | `simulation/dhita_geometry_spec_v2.md` |
| 2026-09-29 | UHF patch becomes a 94 mm **shorted quarter-wave** patch on the curved board | Footprint reduction; trades gain directly against size (v1 170.4 mm patch: 6.84 dBi; v2: −0.96 dBi) | `simulation/dhita_geometry_spec_v2.md` |

## Practices that changed

- Lesson #3 (2026-09-27) says "never use Boolean". The v2 sphere-shell method (2026-09-29) relies on Boolean Subtract / Intersect / Insert / Add. The lessons file has not been updated to reflect this.

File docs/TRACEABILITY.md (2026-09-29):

# Requirement Traceability

Requirement → design response → evidence in this repo → gap. "Sim" means CST simulation only; nothing has been measured.

| SIH26185 requirement | Design response | Evidence so far | Gap |
|---|---|---|---|
| Helmet integration | External side-mounted flex assembly (Design 3), no cutting into the shell | Helmet shell modelled in v2 | Helmet model / mounting method `[TO BE CLARIFIED]`; not physically built |
| Low / zero profile, flexible, conformal | Kapton flex, 3.5 mm stack, curved parts (v2) | Sim v2 | 3.5 mm realisation (foam/silicone) open; flattening needs relief cuts / gores |
| Lightweight, ultra-thin | Passive, no enclosure | — | Mass and thickness limits not stated; nothing weighed |
| UHF support | Probe-fed patch (v1); shorted quarter-wave patch (v2) | v1: 460 MHz, −9.6 dB, 6.84 dBi. v2: 422 MHz, −7.6 dB, −0.96 dBi | v2 fails match and gain; bandwidth never measured |
| L-band support | Half-wave patch, probe-fed | v1: 1364 MHz, −10.15 dB, 7.39 dBi, ~35 MHz. v2: 6.36 dBi | Exact band `[TO BE CLARIFIED]`; v2 S11 marker TBC |
| Underside RF shielding | Continuous ground plane at Z = 0 | Modelled as PEC in both versions | No head-directed-radiation result; head model not documented; shield material TBC |
| Upward / outward radiation | Patches face outward, ground faces head | Directivity values only | No pattern plots in repo |
| High gain | Thick substrate, probe feed | See UHF / L-band rows | Numeric target not stated |
| Ruggedized coax along helmet | U.FL + 50 Ω pigtail to bulkhead | Parts list | Bulkhead type TBC; strain relief untested |
| Connect to existing radios / body-worn video | Independent U.FL output per band | — | Equipment models and connectors `[TO BE CLARIFIED]` |
| No degradation of ballistic protection | No cutting or drilling of the shell | — | No validation method defined |

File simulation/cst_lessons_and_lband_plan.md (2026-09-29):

# D-HITA — CST Lessons Learned (UHF) + L-band Build Plan

**Updated:** 27 Sep 2026
**Hard constraint:** 24 hours to finish UHF + L-band + conform to helmet + 3D sim with real helmet and head. Every step below is picked for speed, not elegance.
**Acceptance rule:** hit the target; if not, within a 30% buffer of target is accepted.

---

## 1. What the UHF run taught us (do not re-learn these)

| # | What happened | Root cause | Rule going forward |
|---|---|---|---|
| 1 | "Mesh cell limit exceeded" (Learning Edition) | Big ground plane + thick metal + default mesh | Zero-thickness metal (patch, ground). Check the mesh cell count in mesh view **before** clicking Start. Confirm the license limit first (seen as both 20k and 100k). |
| 2 | Port "inside metal" / staircasing error | Port Z2 didn't match substrate top after thickness change | Port Z1 = ground (0), Z2 = substrate top. Every time. |
| 3 | Boolean subtract deleted the Patch / cut the Substrate | CST selection order in Boolean dialogs | **Never use Boolean.** Build shapes from separate bricks, or avoid needing a notch at all. |
| 4 | Textbook W/L on Kapton overshot (landed 372 MHz instead of 436) | Closed-form formulas are approximate on thin substrates | Treat formula dims as a start; parametrise L and sweep it once. |
| 5 | Efficiency ~14% even on low-loss Kapton | Substrate electrically too thin (h/λ ≈ 0.0003). 88% of power lost in dielectric, 0 in metal | **h/λ ≥ 0.02.** Thickness is the efficiency lever, not tan δ. |
| 6 | 5 mm substrate → 84% rad. eff., +5.45 dBi gain | Fix for #5 confirmed | Use the same 5 mm stack for L-band so both bands share one build-up. |
| 7 | Stack "disconnected" (S11 ≈ 0 dB, −48 dB eff.) | Set substrate Zmin=3 instead of 0 | Ground Z=0, substrate Zmin=0 → Zmax=h, patch/feed/port-top at Z=h. |
| 8 | Inset feed on 5 mm substrate barely matched (S11 −3.6 → −4.2 dB) | Inset microstrip feed is the wrong tool on a thick substrate | **Use a probe (vertical) feed** — discrete port from ground to patch. No feedline, no notch, no Boolean. Match by moving one X coordinate. |
| 9 | Farfield reported at stale 436 MHz after resonance moved to 448 | Monitor frequency not updated | After every run: read S11 dip → set farfield + power-loss monitors to that frequency → rerun. |
| 10 | Mismatch vs loss confusion | Only looking at S11 | Always read Rad. Eff. vs Tot. Eff.: gap = mismatch; low Rad. Eff. = loss. |

---

## 2. L-band targets

Design centre **1.35 GHz** (band assumption 1.30–1.40 GHz, NSG spec still TO BE CLARIFIED).

| Metric | Target | Accepted (30% buffer) |
|---|---|---|
| Resonance | 1.35 GHz | 1.30–1.40 GHz |
| S11 at resonance | ≤ −10 dB | ≤ −7 dB |
| Rad. efficiency | ≥ 50% (−3 dB) | ≥ 35% (−4.6 dB) |
| Gain | ≥ 5 dBi | ≥ 3.5 dBi |
| −10 dB bandwidth | ≥ 40 MHz | ≥ 28 MHz |

Known limit: a single patch on this stack gives roughly 2–3% bandwidth (~30–40 MHz). It will **not** cover all of 1.30–1.40 GHz. Fine for one video channel; not fine if the full 100 MHz is mandatory.

---

## 3. L-band geometry (Kapton_flex εr=3.5, tan δ=0.002, h=5 mm)

Calculated: λ = 222 mm, h/λ = 0.0225 (passes lesson #5), εeff = 3.18.

| Item | Value (mm) | CST coordinates |
|---|---|---|
| Ground (zero thickness, PEC) | 130 × 130 | X −65..65, Y −65..65, Z 0..0 |
| Substrate (Kapton_flex) | 130 × 130 × 5 | X −65..65, Y −65..65, Z 0..5 |
| Patch (zero thickness, PEC) | L = 57.5 (X), W = 74 (Y) | X −28.75..28.75, Y −37..37, Z 5..5 |
| Probe feed (discrete port) | 10 mm off centre along X (resonant length) | X = 10, Y = 0, Z1 = 0, Z2 = 5 |

Parametrise in CST: `L = 57.5`, `W = 74`, `h = 5`, `px = 10`. Use the parameters in the brick fields so tuning is one number change, not rebuilding bricks.

---

## 4. Run order (L-band)

1. New project, same template (Planar, Frequency Domain). Units as in `cst_software_settings.md`.
2. Frequency range **1.0–1.7 GHz**. Monitors: farfield + power loss at 1.35 GHz.
3. Build ground → substrate → patch with the table above. No feedline.
4. Discrete edge port, 50 Ω, vertical at (px, 0), Z 0 → 5.
5. Mesh view → read the cell count → only then Start.
6. Read S11 dip:
   - Resonance off? Scale L: `L_new = L × (f_got / 1.35)`. One step, rerun.
   - Match off? Sweep `px` 6 → 16 mm in 2 mm steps and keep the best S11. (Toward the edge raises input impedance, toward the centre lowers it.)
7. Update monitors to the actual resonance (lesson #9), rerun, record S11, Rad. Eff., Tot. Eff., gain.
8. Stop when section 2 targets (or buffer) are met. Move on — no polishing.

---

## 5. Open debt (logged, not solved today)

- 5 mm solid Kapton does not exist as a flex laminate. Fabrication equivalent: thin Kapton patch layer on a flexible foam/silicone spacer. Re-check after the helmet sim.
- UHF on 5 mm still needs its match fixed — apply the same probe-feed change (lesson #8).
- L-band exact endpoints still TO BE CLARIFIED.

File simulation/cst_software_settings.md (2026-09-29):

# CST Studio Suite Settings Reference

This document contains the configuration and material settings extracted from CST Studio Suite. It can be used to guide AI or users in replicating or understanding the specific project setup.

## 1. Project Units
*   **Dimensions:** mm
*   **Frequency:** GHz
*   **Voltage:** V
*   **Conductance:** S
*   **Inductance:** nH
*   **Temperature:** °C
*   **Time:** ns
*   **Current:** A
*   **Resistance:** Ohm
*   **Capacitance:** pF

---

## 2. Material Settings: `FR4_substrate`

### General Tab
*   **Material name:** FR4_substrate
*   **Material folder:** [Empty]
*   **Problem type:** Default
*   **Type:** Normal
*   **Epsilon:** 1
*   **Mu:** 1
*   **Color:** Cyan (Light Blue)
*   **Transparency:** 0%
*   **Draw as wireframe:** Unchecked
*   **Draw reflective surface:** Unchecked
*   **Allow outline display:** Checked
*   **Draw outline for transparent shapes:** Unchecked
*   **Add to material library:** Unchecked

### Conductivity Tab
*   **Electric conductivity:** Checked (`El. conductivity`) -> `0 S/m`
*   **Magnetic conductivity:** Checked (`Mag. conductivity`) -> `0 1/Sm`
*   **Advanced parameters:** Unchecked
*   **Tangent delta el. / mag.:** Unchecked
*   **Frequency range [MHz]:** Fmin: `300`, Fmax: `550`

### Dispersion Tab
*   **Dielectric dispersion:** `Disp. model` -> `None`
*   **Magnetic dispersion:** `Disp. model` -> `None`
*   **Parameter conversion System:** Gauss
*   **Parameter conversion Frequency:** 0.0 MHz
*   **Biasing field:** Homogeneous field

### Thermal Tab
*   **General Type:** Normal
*   **Nonlinear:** Unchecked
*   **Thermal conductivity:** 0 W/K/m
*   **Specific heat:** 0 J/K/kg
*   **Material density (Rho):** 0 kg/m³
*   **Thermal diffusivity:** [Empty] m²/s
*   **Dynamic viscosity:** 0 Pa.s
*   **Emissivity:** Checked -> `0`
*   **Thermal expansion coefficient:** 0.0 1e-6 / K
*   **Bioheat - Bloodflow coefficient:** 0 W/K/m³
*   **Bioheat - Basal metabolic rate:** 0.0 W/m³
*   **Bioheat - Convection transfer coefficient (Voxel model):** 0.0 W/m²/K
*   **Solar radiation model - Type:** Opaque
*   **Solar radiation model - Absorptance:** 0.0

### Mechanics Tab
*   **Type:** Unused
*   **Young's modulus:** 0 GPa
*   **Poisson's ratio:** 0.0
*   **Thermal expansion coefficient:** 0.0 1e-6 / K
*   **Material density info:** 0 kg/m³

### Density Tab
*   **Material density Rho:** 0 kg/m³
*   **Buoyancy model Type:** Boussinesq
*   **Thermal expansion coefficient:** 0.0 1e-6 / K

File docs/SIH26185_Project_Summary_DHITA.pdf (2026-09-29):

SIH26185 · D-HITA Project Summary | Page 1

# SIH26185 PROJECT SUMMARY

Lightweight Dual-Band Helmet-Integrated Tactical Antenna (D-HITA)

Problem: Helmet mounted conformal antenna for tactical communications in urban CQB environments

Organization: Ministry of Home Affairs · National Security Guard (NSG), Police II Division

Category: Hardware · Theme: Robotics and Drones

Coverage: Project work and decisions through September 2026

Purpose: Single handover-ready record of requirements, research, engineering decisions, work completed, current status and next actions.

Confirmed source information is separated from engineering assumptions and future work. Unresolved items are marked [TO BE CLARIFIED].

## 1. PROJECT OVERVIEW

### 1.1 Problem Statement

SIH26185 addresses tactical communications for NSG commandos operating in restrictive urban CQB environments such as closed rooms, basements, narrow corridors and stairwells. The PS identifies vest-mounted handheld radios with rigid, protruding omnidirectional whip antennas as causing snagging/obstruction and RF limitations. In reinforced-concrete or steel/glass buildings, low antenna positioning can cause attenuation/fading; omnidirectional radiation can also increase vulnerability to eavesdropping or directional tracking. The PS therefore calls for moving the antenna to the helmet while maintaining a low-profile form and ballistic integrity.

The expected solution is a ruggedized, zero-profile wearable antenna using lightweight, ultra-thin, flexible microstrip patch elements integrated with tactical ballistic helmets; support UHF and L-band operation; use underside RF shielding to isolate the head and direct radiation upward/outward; and route a ruggedized coaxial interface cleanly along the helmet to existing NSG handheld radios and body-worn camera systems.

Source: SIH26185 problem statement, reviewed 10 September 2026. citeturn0search3

### 1.2 Exact PS requirements

Requirement | Confirmed PS meaning
Helmet integration | Integrate seamlessly into/on tactical ballistic helmets.
Low / zero profile | Low-profile; ruggedized zero-profile/minimal protrusion.
Flexible / conformal | Flexible elements that conform to helmet geometry.
Lightweight / ultra-thin | Lightweight, ultra-thin microstrip patch elements.
Conformal array | Expected solution is a conformal antenna array.
UHF | Must support UHF; exact numerical endpoints are not stated.
L-band | Must support L-band; exact numerical endpoints are not stated.
RF shielding | Underside shielding to isolate the head from radiation.
Radiation direction | Optimized radiation pattern upward and outward.
High gain | Problem description calls for high gain; numeric target not stated.
Ruggedized construction | Ruggedized wearable antenna system.
Coax interface | Ruggedized coax routed cleanly along helmet.
Existing equipment | Direct connection to existing handheld radios and body-worn camera systems.
Live video context | UHF/L-band intended to support radio and camera/live-video equipment.
Protection | Must not degrade ballistic or impact protection ratings.
Important: The PS does not state 300 MHz–3 GHz, nor exact gain, bandwidth, range, substrate, shield material, connector, dimensions or weight. These remain engineering targets to be derived. [TO BE CLARIFIED]

### 1.3 Project title and objectives

- Preferred title: Lightweight Dual-Band Helmet-Integrated Tactical Antenna
- Acronym: D-HITA — Dual-band Helmet-Integrated Tactical Antenna.
- Develop a low-profile, flexible, conformal antenna architecture for ballistic-helmet integration.
- Target UHF + L-band while preserving helmet protective function.
- Use shielding and geometry to reduce inward radiation and favor upward/outward coverage.
- Connect to existing equipment through ruggedized coax.
- Validate through EM simulation, fabrication and RF measurement.

### 1.4 Team composition

A final named team roster is not present in the available record. Proposed roles: RF/EM, simulation/optimization, mechanical/CAD, fabrication/electronics, testing, research/documentation, system lead. [TO BE CLARIFIED]

## 2. INITIAL ANALYSIS & REQUIREMENTS

### 2.1 Initial analysis

- Treat the problem as an RF + mechanical integration problem rather than a software project.
- Use the helmet as the highest practical mounting point while avoiding a protruding whip.
- Use a passive antenna baseline; no dedicated helmet battery, MCU or power amplifier is required in the baseline concept.
- Balance low profile, flexibility, conformality, UHF physical size, L-band operation, shielding, gain, bandwidth and helmet area.
- Do not claim novelty before comparing against prior art; reproduce a credible baseline first and then engineer measurable improvements.

### 2.2 Working technical requirements

Area | Working requirement | Status
RF | UHF + L-band | PS confirmed; endpoints [TO BE CLARIFIED]
Interface | 50 Ω RF path | Engineering target
Form | Flexible, conformal patch/array | PS-derived
Profile | Minimal protrusion | PS-derived; thickness [TO BE CLARIFIED]
Shield | Conductive underside layer | PS-derived; geometry/material [TO BE CLARIFIED]
Radiation | Upward/outward, high gain | PS-derived; numeric targets [TO BE CLARIFIED]
Feed | Ruggedized coax | PS-derived; connector [TO BE CLARIFIED]
Testing | S11/VSWR, bandwidth, gain, efficiency, pattern; SAR if feasible | Planned

### 2.3 Constraints

- Ballistic and impact protection cannot be degraded.
- Minimal protruding hardware to reduce snagging.
- Helmet curvature and head loading must be included in later simulation.
- Shielding is a trade-off: it can reduce head-directed fields but can also detune/reduce efficiency.
- UHF wavelengths make compact antennas difficult; loading, slots, meanders, PIFA/folded or multi-resonant approaches may be needed.
- Baseline integration avoids drilling/cutting the protective shell; mounting method remains [TO BE CLARIFIED].

### 2.4 KPIs

KPI | Evidence
Resonance | Target-band resonant frequency
S11 / VSWR | Measured and simulated matching; threshold [TO BE CLARIFIED]
Bandwidth | Frequency span meeting matching criterion
Gain / efficiency | Measured/simulated values; targets [TO BE CLARIFIED]
Radiation | Upward/outward pattern and reduced head-directed radiation
Size/profile/weight | Helmet footprint, thickness and mass; limits [TO BE CLARIFIED]
Ruggedness | Mechanical/environmental validation plan [TO BE CLARIFIED]

## 3. WORK COMPLETED (CHRONOLOGICAL ORDER)

### 3.1 Problem analysis and requirement freeze

Early September 2026: SIH26185 was re-read and converted into a requirement checklist. A key correction was made: the official PS gives only UHF and L-band, not a 300 MHz–3 GHz range.

### 3.2 SIH presentation and project documentation

- A six-slide SIH-style structure was developed: title, proposed solution, technical approach, feasibility/viability, impact/benefits, research/references.
- An internal project-bible approach was established covering architecture, RF basics, components, simulation, risks, roles, Q&A; and checklists.
- The uploaded Recommended Presentation Flow emphasizes problem → solution → technical approach → architecture → technology stack → innovation → feasibility → impact → references, with visual evidence over heavy text. fileciteturn8file0

### 3.3 Research completed

Reference | Role in project

Herold, Griffiths, Fung et al., IEEE MILCOM 2007, “Lightweight, High-Bandwidth Conformal Antenna System for Ballistic Helmets.” DOI 10.1109/MILCOM.2007.4455055 Direct ballistic-helmet conformal antenna prior art.

Lebaric & Tan, IEEE MILCOM 2000, “Ultra-wideband RF helmet antenna.” DOI 10.1109/MILCOM.2000.905081 Early helmet antenna prior art.

Li et al., 2023, “Research Progress on Helmet Antenna in Individual Soldier Communication System.” DOI 10.11999/JEIT220613 Helmet antenna review/background.

Nepa & Rogier, IEEE AP Magazine 2015. DOI 10.1109/MAP.2015.2472374Wearable/conformal antenna background.

Tang et al., IEEE TAP 2025, “A Helmet-Based Hemispherical-Conformal Wearable Array Antenna …” DOI 10.1109/TAP.2025.3560181 Recent helmet conformal-array prior art; full title to re-verify.
Research conclusion: the five papers already read are enough to move into a structured comparison and baseline selection. More papers should be searched only for missing evidence, such as UHF helmet antennas, dual-band UHF/L-band designs, shielding/head loading, and patents.

### 3.4 NSG procurement/equipment investigation

NSG's public tender archive lists Digital UHF Hand Held Radio Sets (20 W and 4 W), a Digital UHF Repeater Set (40 W), and a Wireless Body Worn Video System in 2026. This supports the operational relevance of UHF radio and body-worn video. citeturn0search0

The accessible evidence did not establish the exact NSG radio frequency range, exact awarded radio model, or exact L-band frequency used by the relevant video equipment. Therefore 400–527 MHz, investigated earlier as a possible Motorola R7 UHF range, must not be treated as the confirmed NSG requirement. [TO BE CLARIFIED]

### 3.5 Architecture and component stack

Baseline stack, outward to inward: protective film → copper antenna → flexible substrate → copper ground/shield → mounting adhesive → helmet shell → head.

Candidate physical components: ballistic-style helmet/shell; flexible dielectric; conductive antenna; conductive shield; dielectric spacer/foam; 50 Ω coax; RF connector; strain relief/cable clips; non-metal adhesive; protective outer layer; optional matching network; flex-PCB feed.

### 3.6 Toolchain and setup

Tool | Purpose
Ansys HFSS Student | Primary EM simulation
CST Studio Suite Learning Edition | Alternative EM simulation
KiCad | PCB/flex-PCB and RF feed layout
SolidWorks / FreeCAD | Helmet CAD/mechanical integration
Abaqus 2026 | Optional mechanical FEA
Python / NumPy / SciPy / Matplotlib | Analysis/optimization
Figma | System diagrams/concept visualization
Keysight ADS | Optional RF/matching work
Abaqus 2026 was installed successfully after resolving its Java requirement. Oracle JDK 21.0.12 was used as the supported Java option; Android Studio's bundled JBR was left untouched. A Dassault Environment Editor was accidentally opened while searching for CST and was identified as unrelated; no environment variables were to be modified.

### 3.7 Prototype methodology defined

Prototype ladder: P0 simulation → P1 flat antenna → P2 curved antenna → P3 helmet-mounted → P4 helmet + head → P5 tested prototype → P6 final demonstrator.

Core workflow: requirements → research → candidate architectures → EM simulation → optimization → helmet/head/shield model → fabrication → VNA/radiation testing → iteration → validation.

## 4. KEY FINDINGS & RESULTS

### 4.1 Findings

- Helmet mounting is intended to raise the antenna relative to the vest-mounted radio and improve the practical propagation geometry.
- The main challenge is the simultaneous satisfaction of UHF + L-band + low profile + flexibility + curvature + shielding + ruggedness + ballistic protection.
- A passive antenna is the correct baseline architecture; no separate helmet battery/electronics are required unless the architecture later becomes active/reconfigurable.
- Shielding should be evaluated as an electromagnetic trade-off, not described as producing zero radiation toward the head.
- Curvature, head loading, cable routing, connector placement and manufacturing tolerance must be included in final validation.
- The strongest project strategy is to reproduce a literature-backed baseline and then show measurable modifications against SIH26185 requirements.

### 4.2 Results not yet available

- No validated numerical UHF/L-band endpoints.
- No HFSS/CST simulation results.
- No S11/VSWR/gain/efficiency/radiation measurements.
- No physical antenna prototype.
- No helmet-mounted RF test.
- No head-phantom/SAR result.
- No final topology or defensible novelty claim.

### 4.3 Requirement comparison

Requirement | Current state
Helmet integration | Architecture defined; not physically built.
Low profile/flexible/conformal | Design direction defined; dimensions/materials not final.
UHF + L-band | Required by PS; endpoints [TO BE CLARIFIED].
Shielding | Layer concept defined; material/geometry not final.
Upward/outward radiation | Objective defined; no proof yet.
High gain | Required; numeric target/evidence [TO BE CLARIFIED].
Rugged coax | Architecture defined; connector selection [TO BE CLARIFIED].
Protection | Constraint recognized; no physical validation yet.
Radio/camera compatibility | Concept defined; exact equipment [TO BE CLARIFIED].

### 4.4 Challenges and resolutions

Challenge | Handling
RF unfamiliarity | Decompose into RF fundamentals, literature, simulation, CAD, fabrication and testing.
Unclear numerical frequencies | Stop using 300 MHz–3 GHz as an official PS requirement; obtain equipment evidence.
Too much literature collection | Five papers are enough to move to comparison; search only for gaps.
Premature novelty claim | Use a validated baseline and measure modifications.
Software setup confusion | Abaqus/JDK issue resolved; Dassault Environment Editor identified as unrelated.

## 5. CURRENT STATUS

### 5.1 Working well

- Problem understanding and requirement decomposition are substantially complete.

- Five relevant papers have been identified and read.
- NSG procurement evidence confirms current UHF handheld-radio and body-worn-video procurement. citeturn0search0
- Simulation, CAD, PCB and analysis tools have been selected and setup has begun.
- Project management is structured around requirements, tasks, research, design, experiments, evidence, decisions, risks and documentation.

### 5.2 What still needs improvement

- Lock exact UHF and L-band frequencies.
- Build the research comparison matrix.
- Identify 3–5 defensible research gaps.
- Select 1–2 baseline architectures.
- Reproduce the baseline in HFSS/CST.
- Define numerical pass/fail thresholds.
- Build helmet CAD and simulate curvature/head/shield.
- Fabricate and VNA-test V1.

### 5.3 Current blockers

- Exact UHF frequency range [TO BE CLARIFIED].
- Exact L-band frequency range [TO BE CLARIFIED].
- Exact NSG radio model(s) [TO BE CLARIFIED].
- Exact body-camera/video RF link [TO BE CLARIFIED].
- Meaning of 'svl equipment' [TO BE CLARIFIED].
- Gain, bandwidth, VSWR/S11, size, thickness and weight limits [TO BE CLARIFIED].
- Helmet model/shell material and approved mounting method [TO BE CLARIFIED].
- Ruggedness/environmental test standard [TO BE CLARIFIED].
- Final team roster [TO BE CLARIFIED].

## 6. NEXT WORKFLOW & ACTION ITEMS

### 6.1 Immediate priorities

P0 – Frequency evidence — Obtain credible UHF/L-band target ranges from equipment specifications, manuals, tender documents or authoritative sources.

P1 – Research matrix — Compare the five papers on frequency, topology, dimensions, substrate, thickness, gain, bandwidth, efficiency, conformality, helmet integration, shielding, testing and limitations.

P2 – Gap analysis — Identify 3–5 gaps created by the combined SIH constraints.

P3 – Baseline selection — Select one primary and one backup antenna architecture.

P4 – Reproduce — Build the published baseline in HFSS/CST and compare to reported behavior.

P5 – Modify — Tune geometry/material/loading to the real target bands.

P6 – Helmet model — Add curvature, shell, shield and head loading.

P7 – Optimize — Run parameter sweeps for resonance, matching, bandwidth, gain, efficiency and pattern.

P8 – Fabricate V1 — Use flexible copper/dielectric or flex PCB.

P9 – VNA — Measure S11, VSWR, resonance and bandwidth.

P10 – Radiation — Measure gain/pattern/efficiency in a suitable lab if available.

P11 – Safety/integration — Evaluate cable routing, mechanical attachment, head exposure and protection constraints.

### 6.2 Timeline

Window | Planned work
Days 1–2 | Frequency evidence + research matrix + requirements freeze.
Days 3–4 | Baseline selection + HFSS/CST reproduction.
Days 5–7 | Dual-band modifications + parameter sweeps.
Week 2 | Curved helmet + shield + head model; select V1.
Week 3 | Fabrication + VNA.
Week 4 | Radiation/efficiency + V2 optimization + documentation.
Long-term goal: final dual-band helmet-integrated demonstrator with simulation-vs-measurement evidence and complete requirement traceability.

## 7. TECHNICAL SPECIFICATIONS

Parameter | Current specification
Antenna | Flexible, low-profile, conformal microstrip patch-based array; exact topology [TO BE CLARIFIED].
Bands | UHF + L-band; numerical endpoints [TO BE CLARIFIED].
Feed | 50 Ω coax; exact connector [TO BE CLARIFIED].
Shield | Conductive underside layer for head isolation and radiation shaping.
Radiation | Upward/outward; high gain; numerical targets [TO BE CLARIFIED].
Profile | Minimal protrusion; thickness [TO BE CLARIFIED].
Weight | Lightweight; maximum [TO BE CLARIFIED].
Substrate | Flexible dielectric; material/thickness [TO BE CLARIFIED].
Helmet | Tactical ballistic helmet; exact model/material [TO BE CLARIFIED].
Power | Passive antenna baseline; no dedicated helmet battery.
Validation | HFSS/CST + VNA + radiation/efficiency; SAR/head phantom if feasible.

### Candidate architectures

- Flexible dual-band microstrip patch
- Conformal PIFA
- Conformal slot
- Dual-resonant patch
- Multi-element conformal array
- Antenna + integrated shielding layer

### Design approach

Use an existing validated antenna as the baseline. A published ~3 GHz conformal design can be studied as an architectural starting point, but moving from ~3 GHz to UHF is not a simple scaling exercise: wavelength grows substantially and the helmet footprint becomes dominant. Compact loading, slots, meanders, shorting/PIFA structures, folded geometries and multi-resonant approaches may therefore be investigated.

## 8. REFERENCES & RESOURCES

### 8.1 Official / operational sources

- SIH26185 problem statement, Ministry of Home Affairs / NSG. citeturn0search3
- NSG tender archive, including Digital UHF Hand Held Radio Sets, UHF repeater and Wireless Body Worn Video System. citeturn0search0

### 8.2 Papers

- Herold, Griffiths, Fung et al., IEEE MILCOM 2007, “Lightweight, High-Bandwidth Conformal Antenna System for Ballistic Helmets.” DOI 10.1109/MILCOM.2007.4455055.
- Lebaric & Tan, IEEE MILCOM 2000, “Ultra-wideband RF helmet antenna.” DOI 10.1109/MILCOM.2000.905081.
- Li et al., 2023, “Research Progress on Helmet Antenna in Individual Soldier Communication System.” DOI 10.11999/JEIT220613.
- Nepa & Rogier, IEEE Antennas & Propagation Magazine, 2015. DOI 10.1109/MAP.2015.2472374.
- Tang et al., IEEE TAP 2025, “A Helmet-Based Hemispherical-Conformal Wearable Array Antenna …” DOI 10.1109/TAP.2025.3560181. Full title [TO BE RE-VERIFIED].

### 8.3 Tools

- Ansys HFSS Student
- CST Studio Suite Learning Edition
- KiCad
- SolidWorks / FreeCAD
- Abaqus 2026
- Python / NumPy / SciPy / Matplotlib
- Figma
- Keysight ADS (optional)

### 8.4 Documentation resources

The uploaded Recommended Presentation Flow emphasizes visual problem/solution framing, technical approach, architecture, technology stack, feasibility, impact, references and evidence. fileciteturn8file0 The uploaded SIH demo presentation was used as a reference for six-slide structure and research/reference presentation. fileciteturn8file4turn8file7

### 8.5 Traceability structure

Requirement → Task → Design → Experiment/Test → Evidence → Decision → Documentation

## APPENDIX – CRITICAL OPEN ITEMS

- Exact UHF range
- Exact L-band range
- Exact radio model(s)
- Exact camera/video RF link
- Meaning of 'svl equipment'
- Gain target
- Bandwidth criterion
- S11/VSWR threshold
- Maximum thickness
- Maximum mass
- Helmet model/material
- Shield material
- Ruggedness/environmental standard

- Ballistic/impact validation method
- Final team roster
- Final antenna topology/fabrication route

END OF PROJECT SUMMARY

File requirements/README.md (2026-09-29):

# Requirements

## SIH26185 requirements (from the problem statement, as summarised in the project PDF §1.2)

| Requirement | Meaning |
|---|---|
| Helmet integration | Integrate seamlessly into/on tactical ballistic helmets |
| Low / zero profile | Minimal protrusion, ruggedized |
| Flexible / conformal | Elements conform to helmet geometry |
| Lightweight, ultra-thin | Microstrip patch elements |
| UHF + L-band | Both must be supported; the PS gives **no** numeric endpoints |
| RF shielding | Underside shield isolates the head |
| Radiation direction | Optimised upward and outward |
| High gain | No numeric target stated |
| Coax interface | Ruggedized coax routed cleanly along the helmet to existing radios and body-worn video |
| Protection | Must not degrade ballistic or impact ratings |

The PS does **not** state 300 MHz–3 GHz, or any gain, bandwidth, range, substrate, shield material, connector, dimension or weight figure. Those are engineering targets derived by the team.

## Working targets

**Acceptance rule:** target, or within a 30 % buffer.

| Metric | UHF | L-band |
|---|---|---|
| Band | 403–470 MHz (sourced, see `sources.md`) | 1350–1450 MHz working assumption (1.30–1.40 GHz in the early plan) — `[TO BE CLARIFIED]` |
| S11 at resonance | ≤ −10 dB (accepted ≤ −7 dB) | ≤ −10 dB (accepted ≤ −7 dB) |
| Radiation efficiency | — | ≥ 50 % (accepted ≥ 35 %) |
| Gain | — | ≥ 5 dBi (accepted ≥ 3.5 dBi) |
| −10 dB bandwidth | not yet defined | ≥ 40 MHz (accepted ≥ 28 MHz) |

L-band figures come from `simulation/cst_lessons_and_lband_plan.md` §2. No equivalent UHF gain/efficiency targets are recorded in the project files.

**UHF band source:** 403–470 MHz is stated in the MHA/CRPF QRs for digital UHF radio sets (June 2025, NSG among the co-signers). Link, verification notes and the NSG 2026 tender list are in [`sources.md`](sources.md).

**L-band caution:** no source gives 1350–1450 MHz (or any other L-band range) as the NSG video link. The NSG body-worn-video tender and the earlier MHA camera QRs describe cellular / Wi-Fi / internet relay, not an L-band RF link. Treat the L-band figures above as placeholders until the intended band is confirmed. See [`sources.md`](sources.md) §3.

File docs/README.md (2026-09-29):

# Documentation index

| File | What it is |
|---|---|
| `SIH26185_Project_Summary_DHITA.pdf` | Handover summary, dated 10 Sep 2026 (problem, requirements, research, plan). **Out of date on simulation status** — it says no CST/HFSS results exist. Also contains stray citation placeholders (e.g. `citeturn0search3`) that should be cleaned before this repo is shared. |
| `DECISION_LOG.md` | Why the design is the way it is: what was rejected and what replaced it |
| `OPEN_ITEMS.md` | Everything still `[TO BE CLARIFIED]` or unmeasured, in one list |
| `TRACEABILITY.md` | SIH26185 requirement → design response → evidence → gap |

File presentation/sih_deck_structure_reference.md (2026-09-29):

# SIH Deck — Structural Reference (layout only, no borrowed content)

Captured from reference screenshots of other teams' SIH decks, for layout ideas when building/rebuilding the D-HITA slide deck. Structure only — none of the source teams' project content is reused here.

## Slide type 1 — Title / Problem / Idea / Solution overview
- Top strip: team name (top-left, in an oval/badge), full title centered, hackathon logo top-right.
- Below title, two columns:
  - Left: **Problem** — 2–3 bold-keyword sentences on the pain point.
  - Right: **Our Idea** — one short paragraph naming the solution and its core mechanism.
- Below that, two columns again:
  - Left: **Proposed Solution** — bullet list, key terms bolded, describing the architecture/approach (e.g. "3-layer" style breakdown).
  - Center: a product/device image or simple diagram.
  - Right: **Innovation / Uniqueness** — bullet list of differentiators, each bolded lead phrase + short explanation.

## Slide type 2 — Technical Approach
- Header bar with slide title.
- Left column: **Hardware & Software** — bullet list, each item bolded component name + one-line role (e.g. "Sensor X: does Y").
- Right column: **Flow Chart** — a boxed process diagram showing data/signal flow with labeled stages and decision branches.
- Bottom strip: repo/demo links (GitHub, YouTube) in a small box, plus a one-line progress status (e.g. "X% of the prototype is completed") called out in bold/red.

## Slide type 3 — Feasibility and Viability
- Four-quadrant grid, divided by a plus-shaped rule:
  - Top-left: **Feasibility** — bullets on technical practicality (what makes it buildable now).
  - Top-right: **Commercial feasibility** — market validation, technical readiness %, timeline, success-likelihood estimate.
  - Bottom-left: **Challenges** — bolded challenge name + one-line detail, short list.
  - Bottom-right: **Strategy** — bolded mitigation/approach name + one-line detail, matched roughly 1:1 against the challenges.

## Slide type 4 — Impact and Benefits
- Two columns:
  - Left: **Direct Impact on Target Users** — one bullet per user group, bolded group name + concrete benefit; followed by a **Strategic Impact** block (national/policy-level framing).
  - Right: **Economic & Strategic Benefits** — bolded metric/claim + one-line detail (cost reduction %, market size, partnership angle), with a small supporting bar chart placed below/beside it.

## Slide type 5 — Research and References
- Header: "Research and References".
- Numbered categories (e.g. Problem Validation, Technical Feasibility, Market & Application Validation), each with lettered sub-items:
  - Source name/publication (bold, italic) + one-line quoted or paraphrased finding + a clickable link line underneath.
- Categorizing references by *what they validate* (problem/technical/market) rather than listing them flat reads stronger than a plain numbered reference list.

## General visual patterns across all slides
- Consistent header bar (title centered or left, hackathon/theme logo top-right, team badge top-left).
- Two-column (or four-quadrant) layouts dominate — dense text is always paired with a visual (image, diagram, or chart) rather than run as a single full-width block.
- Bold lead phrases at the start of bullets, not full bolded sentences — keeps scanability high.
- One consistent accent color per deck, used for headers, dividers, and callout boxes.
- Slide numbers bottom-right/bottom-left; page footer accent bar at the very bottom in some decks.

**Status:** noted for later use — not yet applied to the D-HITA deck. When ready, map D-HITA's existing 6 slides (title, proposed solution, technical approach, feasibility/viability, impact/benefits, research/references) onto slide types 1–5 above.

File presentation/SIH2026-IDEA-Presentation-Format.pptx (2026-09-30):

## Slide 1


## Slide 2


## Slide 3


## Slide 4


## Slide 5


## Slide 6


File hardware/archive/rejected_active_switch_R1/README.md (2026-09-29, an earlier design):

# Archive — rejected active-switch design (R1)

`d-hita_rf_frontend_VISUAL_R1_REJECTED.png` is a render of the **first** RF frontend concept: a rigid enclosure holding an SKY13350 RF switch, ESP32-C3 MCU, TP4056 Li-Po charger, TPS63030 regulator, Li-Po battery and USB-C port on Rogers 4350B.

**This design was rejected on 2026-09-28 and must not be built.** It was replaced by the passive dual-feed Kapton-flex design (R2): no switch, MCU, battery, firmware or enclosure. Reasons are in `../../../docs/DECISION_LOG.md`, and the full list of removed parts is in `../../d-hita_rf_frontend_CONFIG.json` under `removedFromPriorRevision`.

Several labels in the image are also garbled or illegible, which is another reason not to use it in the submission.

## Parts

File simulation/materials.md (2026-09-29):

# CST Material Definitions — `Kapton_flex`, `Aramid`, PEC

**Read this first:** these are *reconstructed* from the parameter values recorded in the project files. They are **not** an export of your actual CST dialogs (those two dialogs were never provided). Open your `.cst` project, compare each field below against what you actually used, and correct this file where they differ. `cst_software_settings.md` is the real dump for `FR4_substrate`, which the final designs do not use.

## Where each material is used

| Material | Used for | Source of values |
|---|---|---|
| `Kapton_flex` | Substrate (both bands, v1 and v2) | `hardware/d-hita_rf_frontend_CONFIG.json`, `cst_lessons_and_lband_plan.md` |
| `Aramid` | Helmet shell (v2) | `dhita_geometry_spec_v2.md` — **assumed**, not vendor-confirmed |
| PEC | Patch, ground plane, shorting wall, probe | both specs |
| Vacuum | Space between the two v2 boards; brick `c` in the shell construction | `dhita_geometry_spec_v2.md` |

## `Kapton_flex`

| Field | Value |
|---|---|
| Material name | Kapton_flex |
| Type | Normal |
| Epsilon (εr) | 3.5 |
| Mu (μr) | 1 |
| Electric conductivity | 0 S/m |
| Magnetic conductivity | 0 1/Sm |
| Tangent delta (el.) | 0.002 |
| Dispersion | None (dielectric and magnetic) |

Notes:
- εr 3.5 and tan δ 0.002 are the simulated values. The solid 3.5 mm layer does not exist as a laminate: the real part is a thin Kapton layer over a foam or silicone spacer (open fabrication item). Re-simulate with a two-layer stack once the spacer material is chosen.
- If you use "Tangent delta el." with a frequency range, make it span the band being simulated (the FR4 dump used 300–550 MHz for UHF; the L-band plan used 1.0–1.7 GHz), or one material per band.
- Thickness lives in the geometry, not the material: h = 3.5 mm in the final designs (5 mm in the early L-band plan).

## `Aramid` (helmet shell, v2)

| Field | Value |
|---|---|
| Material name | Aramid |
| Type | Normal |
| Epsilon (εr) | 3.8 |
| Mu (μr) | 1 |
| Electric conductivity | 0 S/m |
| Tangent delta (el.) | 0.02 |
| Dispersion | None |

Notes:
- **Assumed.** Replace with vendor or measured data for the real helmet shell when the helmet model is known (`[TO BE CLARIFIED]`).
- The v2 spec attributes about half the input power lost at UHF to this material, so this one number strongly drives the UHF gain result. Sweep tan δ (for example 0.005 to 0.03) before drawing conclusions about the UHF antenna.

## PEC

Patch, ground and shorting wall are PEC. Ground and patch are zero-thickness in v1; in v2 they are 1 mm shells (`tc = 1`). Note that PEC ignores copper loss, so all conductor loss is missing from the reported radiation efficiencies. Real etched copper on flex will be slightly worse.

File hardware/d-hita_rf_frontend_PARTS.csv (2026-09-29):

Name | Product Name | Description | Category | Type | Quantity | Estimated Cost | Total Cost | URL
UHF Radiating Patch | Etched copper on Kapton flex top layer | UHF radiating element, 170.4 x 148.8 mm, zero-thickness PEC at Z = 3.5 mm, centred at Y = 0. Probe-fed 30 mm off centre. Formed in the flex artwork, not purchased. | electrical | other | 1 | 0.00 | 0.00 | N/A - part of flex fabrication
UHF Probe Feed Via | Plated via through substrate | Probe transition from the UHF patch at Z = 3.5 mm to the ground reference at Z = 0, at (X = 30, Y = 0). Formed in the flex stackup, not purchased. | electrical | other | 1 | 0.00 | 0.00 | N/A - part of flex fabrication
UHF Matching Pad Site | 0402 pad cluster - 0 ohm series jumper populated, 2 shunt positions DNP | Three-position matching site for the 460 MHz feed. Series populated 0 ohm; shunt positions left empty until VNA trimming. Values determined empirically, not pre-calculated. | electrical | other | 1 | 0.30 | 0.30 | N/A - see trim kit below
UHF Radio U.FL | Hirose U.FL-R-SMT-1(10) | Miniature surface-mount coaxial connector, UHF output to the handheld radio. | electrical | module | 1 | 1.25 | 1.25 | https://www.digikey.com/en/products/detail/hirose-electric-co-ltd/U.FL-R-SMT-1-10/1126786
UHF Coax Pigtail | 50 ohm ruggedized coax, U.FL plug to bulkhead | 50 ohm coaxial pigtail routed along the helmet shell to the bulkhead connector. Length set at mechanical integration. Bulkhead type SMA vs TNC [TO BE CLARIFIED]. | electrical | other | 1 | 3.50 | 3.50 | N/A - connector type pending
L-Band Radiating Patch | Etched copper on Kapton flex top layer | L-band radiating element, 55.1 x 74 mm, zero-thickness PEC at Z = 3.5 mm, centred at Y = 250. Probe-fed 16 mm off centre. Formed in the flex artwork, not purchased. | electrical | other | 1 | 0.00 | 0.00 | N/A - part of flex fabrication
L-Band Probe Feed Via | Plated via through substrate | Probe transition from the L-band patch at Z = 3.5 mm to the ground reference at Z = 0, at (X = 16, Y = 250). Formed in the flex stackup, not purchased. | electrical | other | 1 | 0.00 | 0.00 | N/A - part of flex fabrication
L-Band Matching Pad Site | 0402 pad cluster - 0 ohm series jumper populated, 2 shunt positions DNP | Three-position matching site for the 1364 MHz feed. Series populated 0 ohm; shunt positions left empty until VNA trimming. | electrical | other | 1 | 0.30 | 0.30 | N/A - see trim kit below
L-Band Video U.FL | Hirose U.FL-R-SMT-1(10) | Miniature surface-mount coaxial connector, L-band output to the body-worn video system. | electrical | module | 1 | 1.25 | 1.25 | https://www.digikey.com/en/products/detail/hirose-electric-co-ltd/U.FL-R-SMT-1-10/1126786
L-Band Coax Pigtail | 50 ohm ruggedized coax, U.FL plug to bulkhead | 50 ohm coaxial pigtail routed along the helmet shell to the bulkhead connector. Bulkhead type SMA vs TNC [TO BE CLARIFIED]. | electrical | other | 1 | 3.50 | 3.50 | N/A - connector type pending
Kapton Flex Substrate | Polyimide flex laminate, er = 3.5, tan d = 0.002, h = 3.5 mm | Shared substrate carrying both patches. 250 x 445 mm. NOTE: solid 3.5 mm Kapton is not a stock product - realise as thin Kapton layer over flexible foam or silicone spacer. OPEN FABRICATION ITEM. | mechanical | other | 1 | 25.00 | 25.00 | N/A - flex fab house quote required
Underside RF Shield / Ground Plane | Continuous copper plane at Z = 0 | Serves as both the patch ground plane and the head-isolation shield required by the SIH26185 problem statement. 250 x 445 mm, no cutouts or voids under either patch. Material and exact geometry [TO BE CLARIFIED]. | mechanical | other | 1 | 2.00 | 2.00 | N/A - part of flex fabrication
Polyimide Protective Coverlay | Dupont Pyralux LF0110 | Flexible polyimide coverlay protecting feed routing, matching sites and U.FL terminations. MUST NOT cover the radiating patch areas - dielectric loading there detunes both bands. | mechanical | other | 1 | 1.50 | 1.50 | https://www.dupont.com
0402 Inductor Trim Kit | Murata LQW15A series assortment | Assorted 0402 high-Q inductors (Q > 30 at operating frequency) for VNA matching trim. Only fitted if measurement shows the straight-through 0 ohm feed is inadequate. | electrical | other | 1 | 12.00 | 12.00 | https://www.digikey.com/en/products/filter/fixed-inductors/71
0402 Capacitor Trim Kit | Murata GRM1555 / TDK C1005 C0G assortment | Assorted 0402 C0G/NP0 capacitors for VNA matching trim. C0G/NP0 only - no X5R or X7R for RF. | electrical | other | 1 | 12.00 | 12.00 | https://www.digikey.com/en/products/filter/ceramic-capacitors/60
0 Ohm 0402 Jumpers | Yageo RC0402 0 ohm | Series-position jumpers for both matching pad sites, giving a straight-through feed as the starting configuration. Buy a strip, not two. | electrical | other | 2 | 0.03 | 0.06 | https://www.digikey.com/en/products/filter/chip-resistor-surface-mount/52

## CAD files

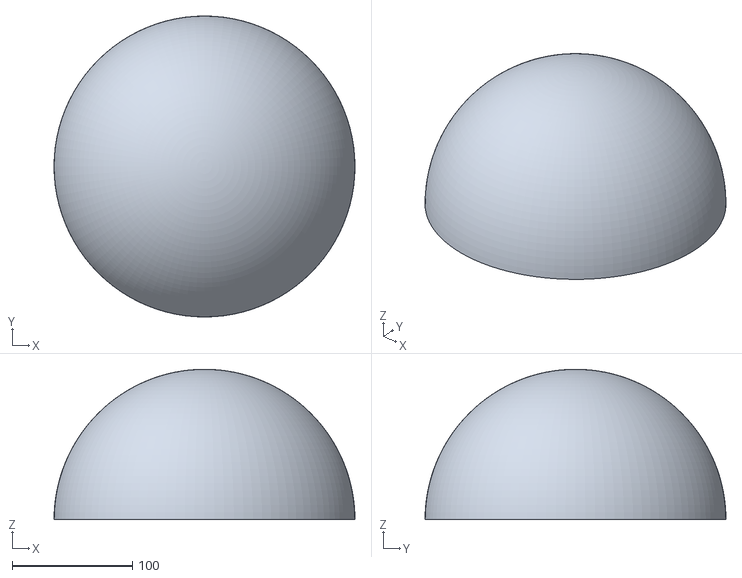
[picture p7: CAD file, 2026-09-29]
simulation/helmet/helmet_shell_R125_t5.6.stl
250.0 x 250.0 x 125.0

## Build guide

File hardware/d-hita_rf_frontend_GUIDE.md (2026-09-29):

# D-HITA RF Frontend — Build Guide (R2, Passive Dual-Feed, Kapton Flex)

**Revision R2 — 28 Sep 2026.** Supersedes the active-switch revision (SKY13350 + ESP32-C3 + Li-Po on Rogers 4350B in an enclosure). That design is **rejected** — do not build it. There is no MCU, no switch, no battery, no firmware, and no enclosure in this build.

**What this is:** two independent probe-fed patches on one Kapton flex sheet. UHF (460 MHz) and L-band (1364 MHz) each have their own feed, their own matching pad site, and their own U.FL output. Both bands are live simultaneously. The board is entirely passive.

---

## Tools
- Flex-capable PCB fabrication (outsourced — see Assumptions)
- Soldering iron with fine tip, or hot air station
- Solder paste (SAC305, or low-temp Bi58Sn42 — preferred for polyimide, lower thermal stress)
- Multimeter with fine probes
- Tweezers (anti-static)
- ESD workstation mat
- **Vector Network Analyzer (VNA)** — mandatory, not optional. The matching pad values are determined on the VNA, not in advance.
- 0402 trim kit: assorted Murata LQW15A inductors and GRM1555 / TDK C1005 C0G capacitors
- Isopropyl alcohol (99%) and lint-free swabs
- Laser cutter or precision knife for coverlay trimming

**No longer needed:** USB-C programming cable, ESP-IDF/Arduino toolchain, solder stencil for Rogers, Li-Po handling equipment.

## Assumptions
- Access to a **flex-PCB** fabrication service (polyimide, not rigid FR-4 or Rogers). This is the key sourcing dependency.
- The 3.5 mm substrate thickness is realised as a thin Kapton patch/feed layer over a flexible foam or silicone spacer — **solid 3.5 mm Kapton laminate is not a stock product.** This remains an open fabrication item and must be settled with the fab house before release.
- Basic SMD hand-soldering skill. Only 0402 passives and two U.FL connectors are hand-placed; there are no QFN or fine-pitch ICs in this build.
- VNA access for post-fabrication matching trim.

---

## 1. Fabrication

### 1.1 Release the flex stackup to the fab house
**Prepare and send the Kapton flex artwork.**

1. Confirm the stackup with the fab house: copper on polyimide top layer (patches + feed routing), 3.5 mm dielectric separation to a continuous copper ground plane. Discuss how they will achieve 3.5 mm — laminated foam spacer, silicone, or stacked polyimide.
2. Board outline: 250 × 445 mm (X −125 to +125, Y −125 to +320).
3. Top layer: UHF patch 170.4 × 148.8 mm centred at Y = 0; L-band patch 55.1 × 74 mm centred at Y = 250. Edge-to-edge separation ~65 mm.
4. Bottom layer: continuous copper ground plane across the full board outline. This is also the head-isolation shield — no cutouts, no voids under the patches.
5. Plated vias: one at (X = 30, Y = 0) for the UHF probe, one at (X = 16, Y = 250) for the L-band probe.
6. Feed routing: 50 Ω microstrip calculated for εr = 3.5 at h = 3.5 mm. Ask the fab house to confirm the trace width against their actual stackup rather than trusting a calculator value.

> **Tip:** The 65 mm patch separation and the 3.5 mm dielectric thickness are the two dimensions that must not be "optimised" by the fab house for panel efficiency. Separation controls inter-band isolation (currently −50 to −90 dB); thickness controls radiation efficiency, and thinning it was what dropped the UHF patch to 14% efficiency in earlier simulation runs.

### 1.2 Inspect the incoming boards
**Verify what arrived matches what was ordered.**

1. Measure both patch dimensions with calipers against the drawing. A few tenths of a millimetre is fine; several millimetres will shift resonance.
2. Measure the actual dielectric thickness at several points. Report any variation over ±0.3 mm — it will change both resonances.
3. Continuity-check the ground plane across the full board. Any break under a patch ruins that patch.
4. Check each probe via for continuity from top pad to ground plane, and confirm it is *not* shorted to the patch copper.
5. Clean both faces with 99% IPA and a lint-free wipe.

> **Tip:** Do this before soldering anything. A board with the wrong dielectric thickness is not worth populating.

### 1.3 Trim the polyimide coverlay
**Cut the coverlay to cover feed routing only.**

1. Cut the 0.025 mm coverlay to cover the two feed-routing corridors, the two matching pad sites, and the U.FL footprints — with cutouts at the connector openings.
2. **Do not cut a piece that covers either radiating patch.** Dielectric loading over a patch detunes it. The patch areas stay bare.
3. Use low power / high speed on a laser cutter to avoid charring, or cut by hand with a fresh blade against a straightedge.
4. Clean any carbonised debris from cut edges.

> **Tip:** If in doubt, make the coverlay smaller. There is no downside to leaving more copper exposed on the feed side; there is a real downside to covering a patch.

---

## 2. Assembly

### 2.1 Populate the matching pad sites — initial configuration
**Fit the 0 Ω jumpers and leave the shunt positions empty.**

1. On both the UHF and L-band matching pad sites, solder a **0 Ω 0402 jumper into the series position**.
2. Leave **both shunt-to-ground positions unpopulated (DNP)** on each site.
3. This gives a straight-through feed, which is the correct starting point — simulation already shows S11 of −9.6 dB (UHF) and −10.15 dB (L-band) without any matching components.
4. Clean flux residue with IPA. Flux left on RF traces on a low-loss substrate causes real dielectric loading.

> **Tip:** The shunt positions exist so the board can be trimmed after measurement. Populating them now with guessed values will make the match worse, not better.

### 2.2 Solder the two U.FL connectors
**Mount UHF Radio U.FL and L-Band Video U.FL.**

1. Place the UHF U.FL at the end of the UHF feed routing (~8 mm past the matching pad site), and the L-band U.FL at the end of the L-band routing (~6 mm past its matching pad).
2. Hand-solder or hot-air reflow. If using reflow on polyimide, prefer a low-temperature Bi58Sn42 profile over SAC305's 245–250 °C peak — polyimide tolerates it, but there is no reason to thermally stress a flex board unnecessarily.
3. Ensure the connector shell ground is properly bonded to the ground plane through the via stitching.
4. Inspect under magnification for bridging between signal pin and shell.
5. Clean all flux with IPA and a lint-free swab.

> **Tip:** U.FL is the most mechanically fragile point on this assembly. Plan strain relief for both pigtails within 20 mm of the connector before the board goes anywhere near a helmet.

### 2.3 Laminate the coverlay
**Apply the trimmed coverlay over the feed regions.**

1. Clean the feed-side surface with IPA.
2. Align the coverlay over the feed corridors and matching sites, with connector cutouts clear.
3. Laminate with even pressure; cure under low heat per the Pyralux datasheet.
4. Confirm again that no coverlay overhangs either radiating patch.

### 2.4 Attach the coax pigtails
**Mate the U.FL pigtails and secure them.**

1. Mate the UHF pigtail to the UHF Radio U.FL and the L-band pigtail to the L-Band Video U.FL. Press vertically — U.FL plugs do not tolerate angled insertion.
2. Route both pigtails along the intended helmet-shell path and secure with non-metallic cable clips.
3. Terminate both at their bulkhead connectors. **Bulkhead connector type (SMA vs TNC) is still [TO BE CLARIFIED]** — confirm against the NSG radio and body-worn video connector interfaces before committing.

---

## 3. Bring-up (VNA)

### 3.1 Measure UHF S11
**Baseline the UHF port against simulation.**

1. Calibrate the VNA over 300–700 MHz at the end of the UHF pigtail (calibrate at the pigtail end, not the connector — the cable is part of the system).
2. Sweep and record the S11 curve.
3. **Expected from simulation:** resonance at ~460 MHz, S11 ≈ −9.6 dB.
4. Record the actual resonant frequency and depth. Expect a shift — the physical substrate realisation differs from the simulated ideal.
5. Measure the −10 dB bandwidth. **This value has never been measured or simulated for UHF** and is the project's one outstanding performance unknown.

> **Tip:** 460 MHz sits inside the confirmed NSG/MHA UHF band of 403–470 MHz, but close to its top edge. If the physical board shifts upward, it leaves the band. If it shifts downward, it moves toward the band centre, which is better. Note which way it went.

### 3.2 Measure L-band S11
**Baseline the L-band port.**

1. Recalibrate over 1200–1600 MHz at the end of the L-band pigtail.
2. Sweep and record.
3. **Expected from simulation:** resonance at ~1364 MHz, S11 ≈ −10.15 dB, −10 dB bandwidth ~35 MHz.
4. Record actual resonance, depth and bandwidth.

### 3.3 Measure port-to-port isolation (S21)
**Confirm the two patches are not coupling badly in hardware.**

1. Connect port 1 to the UHF pigtail and port 2 to the L-band pigtail.
2. Sweep 300–1700 MHz and record S21.
3. **Expected from simulation:** −50 to −90 dB across most of the range, with a worst case of −30 to −40 dB in the 900–1200 MHz dead zone between bands.
4. If measured isolation is worse than −25 dB anywhere in either operating band, stop and investigate before proceeding — it usually means a ground plane defect rather than a spacing problem.

### 3.4 Trim the matching networks
**Populate shunt components only where measurement says to.**

1. Work one band at a time. Do not trim both simultaneously — you will not know which change caused which effect.
2. If S11 at the target frequency is already ≤ −10 dB, **leave the 0 Ω jumper alone and populate nothing.** A good match needs no matching network.
3. If S11 is inadequate, use the Smith chart to determine whether a shunt capacitor or shunt inductor is needed, and fit a single 0402 component into one shunt position.
4. Re-measure after every single component change. Record the value fitted and the resulting S11.
5. If the series position needs to become reactive, replace the 0 Ω jumper with the required series component.
6. Keep a written log of every trial value — this log is the fabrication record for V2.

> **Tip:** Resist the temptation to chase the last decibel. The project acceptance rule is target or within a 30% buffer. S11 of −7 dB clears the buffer on both bands.

---

## 4. Integration and Validation

### 4.1 Mount to the helmet
**External side-mounted configuration (Design 3).**

1. Mount the flex assembly on the *outside* of the helmet shell — no cutting into the shell, no internal cavity access.
2. Ground plane / shield faces the helmet and head; patches face outward.
3. Use non-metallic adhesive. Metallic fasteners through the board will corrupt the ground plane and detune both bands.
4. Route both coax pigtails cleanly along the shell with strain relief at the board end.

### 4.2 Re-measure on the helmet
**The helmet and head change the antenna. Measure again.**

1. Repeat 3.1, 3.2 and 3.3 with the assembly mounted on the helmet, and again with the helmet worn or on a head phantom.
2. Expect resonance to shift and efficiency to drop — the flat, free-space numbers are not the on-helmet numbers.
3. Record both conditions. The simulation-vs-measurement comparison across flat / curved / on-head is the core evidence deliverable for SIH26185.

> **Tip:** Conformal (curved) simulation and the helmet + head model have **not yet been run**. The flat design is complete and passes on both bands; curvature and head loading are the next simulation phase and the measurements here are what validate them.

### 4.3 Radiation measurement (if lab access allows)
1. Measure gain and radiation pattern for both bands if an anechoic chamber or suitable range is available.
2. **Expected from simulation:** UHF gain 6.84 dBi, radiation efficiency ~74%; L-band gain 7.39 dBi, radiation efficiency ~92%.
3. Confirm the pattern favours upward/outward radiation with reduced head-directed energy — this is a direct SIH26185 problem-statement requirement.

---

## Known open items
- Exact NSG L-band video link frequency **[TO BE CLARIFIED]** — 1350–1450 MHz is a working assumption
- 3.5 mm flexible substrate realisation (Kapton over foam/silicone spacer) — open fabrication item
- Ruggedized bulkhead connector selection, SMA vs TNC **[TO BE CLARIFIED]**
- RF shield material and exact geometry **[TO BE CLARIFIED]**
- Helmet model, shell material, approved mounting method **[TO BE CLARIFIED]**
- UHF −10 dB bandwidth — never measured, carried as known debt
- Conformal and helmet + head simulation — not yet run

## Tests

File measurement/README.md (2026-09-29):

# Measurement

**Nothing has been measured yet.** All numbers in this repo are CST simulation results.

The VNA procedure is in `../hardware/d-hita_rf_frontend_GUIDE.md` §3 (S11 for each band, S21 isolation, matching trim) and §4 (on-helmet and on-head re-measurement, radiation).

Measure and record each band under three conditions so simulation and measurement can be compared: **flat / free space**, **on the helmet**, **helmet worn or on a head phantom**.

## Templates (`templates/`)

- `s11_log_template.csv` — one row per measurement
- `trim_log_template.csv` — one row per matching-component change (this log is the fabrication record for V2; re-measure after every single change)

Suggested layout for raw data: `measurement/data/<date>_<band>_<condition>.s1p` (or `.s2p` for S21).

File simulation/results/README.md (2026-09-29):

# Simulation results

Empty so far. Please add, per configuration (UHF standalone, L-band standalone, v1 flat combined, v2 curved):

- S-parameters as Touchstone (`.s1p` / `.s2p`) or CSV — S11, S22, S21
- Farfield pattern exports and 3D pattern screenshots
- Efficiency / gain tables (radiation, total, IEEE gain, realized gain)
- A `results_summary.md` recording S11 minimum, resonance, efficiencies, gain and −10 dB bandwidth for each run

Suggested naming: `v1_flat_uhf_s11.csv`, `v2_curved_lband_farfield_1364MHz.txt`, and so on.

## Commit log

2026-09-29 Initial D-HITA repository: docs, simulation, hardware, analysis
    Project docs, CST notes and geometry spec v2, R2 hardware files, PARTS.csv,
    flatten_dimensions.py, folder READMEs and measurement log templates.
    Rejected R1 active-switch render archived under hardware/archive.
    Claude-Session: https://claude.ai/code/session_01LCgpXe2dxrDfsgy1St9LqJ
    [d-hita_rf_frontend_PARTS.csv, s11_log_template.csv, trim_log_template.csv]
2026-09-29 Add sources, materials, helmet model, analysis tools, team template
    - requirements/sources.md: UHF 403-470 MHz primary source, NSG 2026 tender
    links, finding that the NSG video tender specifies cellular/internet relay
    (no L-band RF link), transmit-power note
    - simulation/materials.md: Kapton_flex, Aramid, PEC (reconstructed from spec)
    - simulation/helmet: helmet shell STL from v2 spec + head-model plan
    - analysis: sparams loader, s11_report, compare_sim_meas, make_helmet_shell,
    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
    [helmet_shell_R125_t5.6.stl]
